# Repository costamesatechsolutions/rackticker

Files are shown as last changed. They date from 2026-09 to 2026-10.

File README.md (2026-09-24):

# RackTicker

**Rack enhancement that fits in 2U.**

**By Pine Heights Ventures LLC dba [Costa Mesa Tech Solutions](https://github.com/costamesatechsolutions)**

RackTicker cycling through its screens on live data

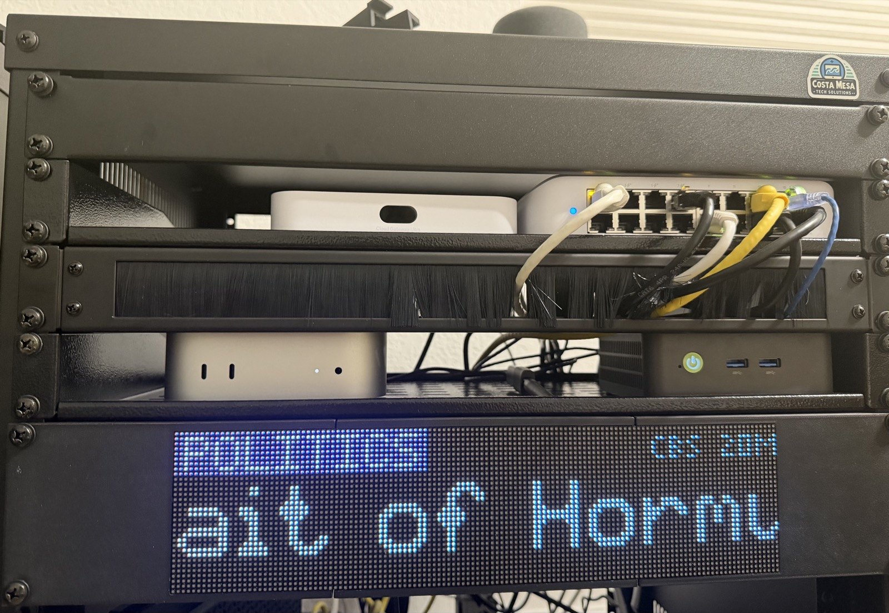
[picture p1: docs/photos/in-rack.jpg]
RackTicker installed in a 19-inch rack


Live LED signage for your server rack. RackTicker turns two 64×32 RGB LED panels and a
Raspberry Pi into a 128×32 ticker that lives in a 19-inch rack: stock tape, odds boards,
news, flights overhead, weather and a pixel town, with more in the community catalog.
Every screen is a plugin, the bundled data sources are free and need no key, and nothing
needs a cloud account. Run it on your computer first: the browser emulator shows the exact
pixels the panels will.

To write your own screen, fork the
**[plugin starter](https://github.com/costamesatechsolutions/rackticker-plugin-starter)**
or run `python -m app.dev new my_plugin`. See [Make a screen](#make-a-screen).

## Screens

| Screen | What it shows |
| --- | --- |
| Stock tape | The day's movers and your watchlist with company names, sparklines and each company's latest headline, under a flipping index header |
| Sportsbook | A Vegas odds board: spreads, totals and moneylines, big live scores with the bases, count and outs or the down and distance, banners for big plays, fireworks when your team scores |
| News desk | Network channels with whole headlines two lines at a time, a TV lower third or a Times Square zipper |
| Flights | The planes overhead: airline mark, flight number and route, then destination, aircraft, altitude and time to go; a list when several are about, a fly-by when one is directly overhead. Local ADS-B receiver or a free network feed |
| Weather | Animated sky, hourly chart and four-day forecast |
| Pixel Town | A small town on real time in three districts: a beach with the real tide and swell, a high street with a taco truck and your weather, and a station with real departures. The panel is a camera that drifts between them. The beach and station use the Surf and Departures plugins when installed |
| Clocks | Desk clock (with a 4:20 surprise) and TIX Clock |

**[Community plugins](https://github.com/costamesatechsolutions/rackticker-community-plugins)** live in their own repository and install from the
Plugins page with one click:

| Plugin | What it shows |
| --- | --- |
| [Departures](https://github.com/costamesatechsolutions/rackticker-community-plugins/tree/main/plugins/departures) | Live station boards: the London Underground in its own line colours, Metrolink and Amtrak across the United States, BART, and Budapest-Keleti, Roma Termini, Milan, Florence, Venice, Naples and Zürich, each in its country's style, with real delays, platforms, station announcements, and trains pulling in |
| [Onboard](https://github.com/costamesatechsolutions/rackticker-community-plugins/tree/main/plugins/onboard) | The strip map above the carriage doors of a train that is really running: the line, its stops, the train sliding along it, the next stop and how long until it |
| [Tanks](https://github.com/costamesatechsolutions/rackticker-community-plugins/tree/main/plugins/tanks) | California's reservoirs, and the space station's urine and water tanks, as sloshing water |
| [Quakes](https://github.com/costamesatechsolutions/rackticker-community-plugins/tree/main/plugins/quakes) | Earthquakes around you from the USGS on a 24-hour seismograph |
| [Surf](https://github.com/costamesatechsolutions/rackticker-community-plugins/tree/main/plugins/surf) | Wave height, swell, water temperature and the tide at your break: the sea sits high or low with the real tide, with the next turn and which way it is going |
| [Now playing](https://github.com/costamesatechsolutions/rackticker-community-plugins/tree/main/plugins/now_playing) | The song you're listening to like an old car stereo: album art, scrolling title, track and time, spectrum analyser. Spotify or Home Assistant |
| [Virtual Aquarium](https://github.com/costamesatechsolutions/rackticker-community-plugins/tree/main/plugins/virtual_aquarium) | A tank of clownfish, angelfish and neon tetras, with swaying plants and a wandering snail |
| [Retro Screensavers](https://github.com/costamesatechsolutions/rackticker-community-plugins/tree/main/plugins/retro_savers) | 3D pipes, Mystify, a starfield, a bouncing badge and marquee text |
| [Arcade](https://github.com/costamesatechsolutions/rackticker-community-plugins/tree/main/plugins/arcade) | Pixel Quest, Tetris, Snake, Breakout, Invaders and Pong, played live by AIs |
| [Formula 1](https://github.com/costamesatechsolutions/rackticker-community-plugins/tree/main/plugins/f1) | A start-light gantry counting down to lights out, the last race's podium and the championship fight |
| [Prediction markets](https://github.com/costamesatechsolutions/rackticker-community-plugins/tree/main/plugins/markets) | Polymarket and Kalshi: each question whole and still, then its odds slide up |
| [LED sign](https://github.com/costamesatechsolutions/rackticker-community-plugins/tree/main/plugins/ticker_wall) | Your own words on a storefront sign: letters that assemble, drop and spin, in taqueria, Vegas, arena and Times Square styles |
| [Freeway traffic](https://github.com/costamesatechsolutions/rackticker-community-plugins/tree/main/plugins/traffic) | California freeways near you: CHP incidents, the real overhead message signs, and travel-time signs as they read over the road |
| [Data from a link](https://github.com/costamesatechsolutions/rackticker-community-plugins/tree/main/plugins/url_data) | Any value from a JSON address as a big card, no code |

Screens finish the headline, card or lap they are showing before the playlist moves
on, skip themselves when they have nothing to show, and move on a frame-locked clock
so crawls step exactly one LED per frame.

## What you need

| Part | Notes |
| --- | --- |
| **Raspberry Pi 3A+** | The reference build. A Pi Zero 2 W should work (untested); the original Zero W is too slow |
| **2 × Waveshare 64×32 P2.5 RGB LED matrix panels** | HUB75, chained side by side: 320 × 80 mm of screen |
| **WatangTech RGB Matrix Adapter Board** | Sits on the Pi's header and drives the panels ("regular" pin mapping) |
| **5 V power supply with a barrel plug** | Sized for your panels; 4 A or more is a good start. Match the adapter's jack |
| **microSD card** | 16 GB or more, Raspberry Pi OS Lite |
| **3D printed 2U rack face** | Four parts and eight M3 × 10 screws; 88 mm of rack height. **[Print files on MakerWorld](https://makerworld.com/en/models/3327605-rackticker-2u-led-ticker-for-your-server-rack)**; guide in [BEZEL_V10.md](hardware/enclosure/BEZEL_V10.md) |
| **USB ADS-B receiver** *(optional)* | An RTL-SDR stick and antenna for planes overhead; without one, Flights uses a free network feed |

The panel frame is always exactly 128×32 RGB. Typography, clipping and motion are
designed at that size, so what the emulator shows is what the panels show.

| The 2U face | Behind it |
| --- | --- |
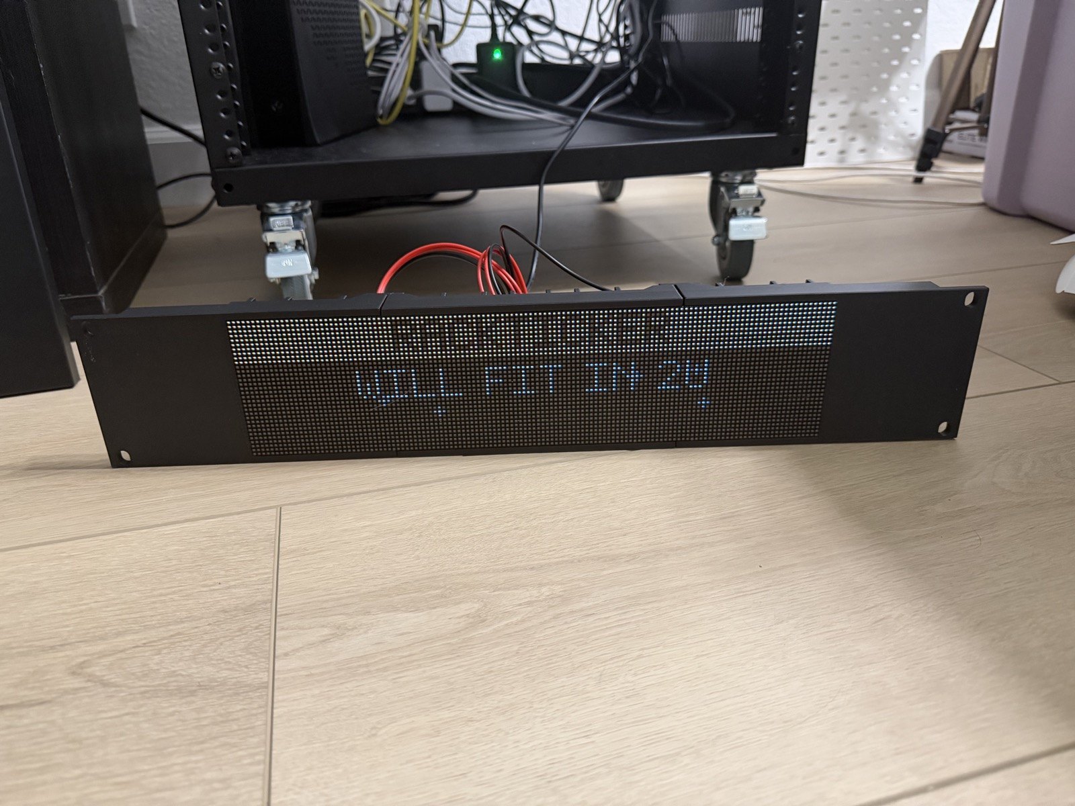
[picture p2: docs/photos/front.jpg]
The printed 2U face
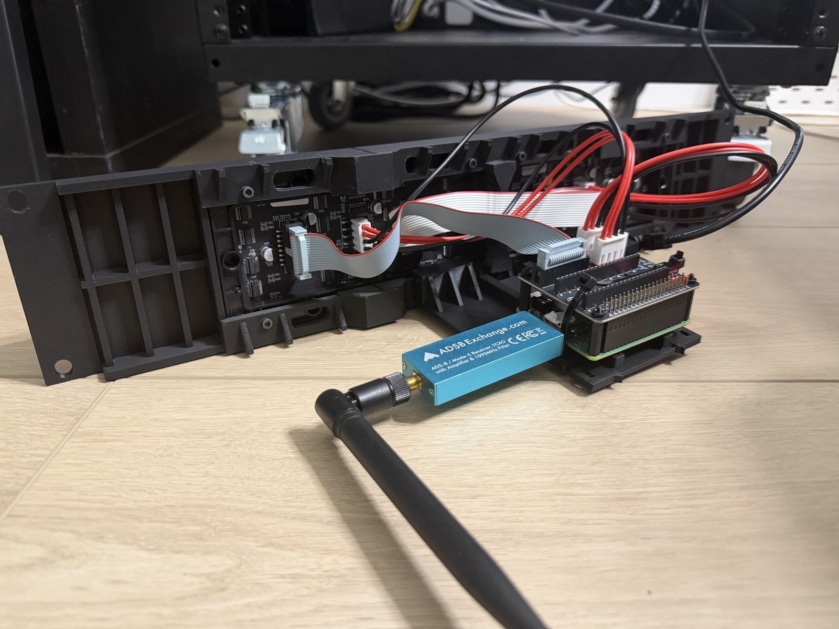
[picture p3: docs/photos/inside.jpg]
The Pi, adapter board and ADS-B receiver behind the face
|  |  |

Two panels, the adapter board on the Pi's header, one barrel jack for power, and
an ADS-B stick if you want the planes overhead to be the ones actually overhead.

The whole build in order, from printing to first light, is in [docs/assembly.md](docs/assembly.md).

## Try it on your computer

Python 3.10 or newer:

```sh
python3 -m venv .venv
source .venv/bin/activate
python -m pip install -r requirements.txt
python -m app
```

Open **http://localhost:8080/**. On your own computer the control page is on port
**8080**. (Installed on a Pi it is on **8081**; see below.) The first run starts a
playlist of real screens and asks where the rack is.

Windows PowerShell:

```powershell
py -3.12 -m venv .venv
.venv\Scripts\python.exe -m pip install -r requirements.txt
.venv\Scripts\python.exe -m app
```

`python -m app --help` lists options (`--port`, `--config`, `--host 0.0.0.0` to
open it to your LAN, `--output hub75` on a Pi).

## Install on a Pi

1. With [Raspberry Pi Imager](https://www.raspberrypi.com/software/), flash **Raspberry Pi
   OS Lite (64-bit)**. Under Edit Settings, set a hostname (for example `rackticker`),
   a user and password, your Wi-Fi, and enable SSH.
2. Boot it, SSH in once, and run:

   ```sh
   curl -fsSL https://raw.githubusercontent.com/costamesatechsolutions/rackticker/main/tools/install.sh | sudo bash
   ```

   It builds the panel driver, reboots, and installs the newest release by itself
   (about ten minutes on a Pi 3A+).

3. **Open the control page at `http://<your-pi>:8081/`** (port 8081, not 8080). The panels
   show the address when they light up, by name and by IP: `rackticker.local:8081` or
   `192.168.1.50:8081`. The name is the hostname you set in the imager. If `.local` does not
   resolve (some Windows and Android setups), use the IP.

That is the last time you need SSH:

- **Updates:** Settings → Software shows when a new version is out; press Update.
  The new version is installed beside the running one, and if it does not come up
  healthy within a minute RackTicker switches back to the old one by itself.
- **Self-healing:** every day, and at boot, RackTicker checks its installed files
  against fingerprints taken at install and repairs anything damaged, from the
  previous version or a fresh download.
- **Wi-Fi setup mode:** with no Wi-Fi saved, or after five minutes without the
  saved one (new router, new password, moved house), the panel shows
  **Wi-Fi setup**: join the `RackTicker-Setup` network with your phone, pick your
  Wi-Fi on the page that opens, and it reconnects. If the old network comes back,
  it rejoins by itself. A working connection is never touched.
- **Reset:** Settings → Software, as far back as you like. *Settings and plugins*
  keeps a backup of your old settings and leaves Wi-Fi alone; *Wi-Fi only* forgets
  the network and opens setup mode, for when RackTicker moves house without you;
  *Everything* clears settings, plugins, the password and Wi-Fi; *Ready to pass on*
  does all of that and then some (see below).
- **Password:** optional, in Settings → Software. Forgot it? Unplug RackTicker as soon
  as its panel lights up, three times in a row; on the next start the panel says
  PASSWORD CLEARED. No computer needed.
- **Crash protection:** if RackTicker keeps stopping, it goes back to the previous version.

### Passing one on, or cloning cards

**Settings → Software → Reset → Ready to pass on** hands a unit over clean. It clears
settings, installed plugins, plugin logins, the control page password and the saved Wi-Fi,
wipes the system log and shell history, and clears the device's own identity (machine id,
ssh host keys and name). Then it powers off; wait for the panel to go dark before
unplugging.

Cards cloned from one image without that step share a machine id, ssh host keys and
`.local` name, so the Pis clash on a network. After *Ready to pass on*, each card's first
boot makes its own and names itself from its Pi's serial number (for example
`rackticker-3c4d`). The panel shows the name and address it settled on.

To make a master card: set one up, reset it *Ready to pass on*, then image the card once
it has powered off.

**Developing from a computer:** `RACKTICKER_PI_HOST=pi@rackticker.local ./tools/deploy_pi.sh`
installs your committed working copy the same way, with the same health check and rollback.

## Panel tuning

The companion accepts every standard `rpi-rgb-led-matrix` `--led-*` flag from
`/etc/rackticker/matrix.conf` (installed once, never overwritten by updates);
restart it with `sudo systemctl restart rackticker-matrix` after editing.

- **Flicker:** the default `--led-limit-refresh=120` holds one steady refresh rate.
  Unlimited, the reference build swung from 208 Hz down to 93 Hz whenever the Pi was
  busy decoding ADS-B, which shows as bursts of flicker. Measure your panel with
  `--led-show-refresh` and keep the limit below its lowest rate.
- **Colours:** press **Settings → Developer tools → Colour test** and check each block matches its label. If
  GREEN shows blue (and amber looks pink), your panels are wired RBG: add
  `--led-rgb-sequence=RBG`.
- **Dim colours:** `--led-pwm-lsb-nanoseconds=160` (the default here) keeps very low
  brightness from drifting pink.
- **Other hardware:** for example an Adafruit bonnet:
  `--led-gpio-mapping=adafruit-hat --led-rows=32 --led-cols=64 --led-chain=2`.

## The control page

- **Now**: the live panel, what is playing, Pause and Next, a tile per screen to
  put it up now, panel on/off, brightness and a quick message.
- **Screens**: the playlist. Switch screens on and off, set their seconds, reorder,
  and open any screen's settings: team pickers by name, league chips, city search.
- **Plugins**: switch plugins on and off, install from a GitHub link or the
  community list, update, restart, remove.
- **Settings**: home location, brightness and night dimming, transitions, Home
  Assistant, and developer tools.

The page is open by default and binds to `127.0.0.1` unless you pass `--host` (the Pi
install passes it, so the page is on your network). Set a password under
Settings → Software if you want one. Everything the page does is also a small JSON
API under `/api/`.

## Home Assistant and voice

Settings → Home Assistant connects RackTicker to an MQTT broker (the Mosquitto
add-on works). It appears in Home Assistant as a device by itself: a light for on/off
and brightness, a Screen picker, a **Show …** switch for every screen, Next and a
Message box. Expose those switches to Alexa or Google through Home Assistant (or its
Matter bridge) and say "turn on Show Sportsbook".

## Make a screen

A plugin is a folder with a `plugin.json` and a Python file; you never edit RackTicker
itself. Fork the
**[plugin starter](https://github.com/costamesatechsolutions/rackticker-plugin-starter)**
or scaffold your own:

```sh
python -m app.dev new surf_report           # a working starting point
python -m app.dev check surf_report         # renders preview.png / preview.gif and reports problems
python -m app.dev preview surf_report       # live in the browser, reloads on save
python -m app.dev push surf_report --to rackticker.local:8081
```

Share it as a folder in a public GitHub repository: anyone installs it by pasting the link
into **Plugins → Add a plugin**, and updates it with one click. Installed plugins run in
their own sandboxed process, so a crash or hang restarts only that plugin and the display
never waits for it. The scaffold includes an `AGENTS.md` with the panel's rules, so an AI
coding agent can build and check a screen on its own. To list yours for everyone, open a
pull request against the
**[community plugins repository](https://github.com/costamesatechsolutions/rackticker-community-plugins)**
with one folder and one catalog entry. Full guide: [docs/plugins.md](docs/plugins.md).

## How it stays smooth

Animation time is counted in integer units, so a 30 px/s crawl at 30 fps moves one
LED every frame for weeks. Data providers run on their own thread and hand feed
parsing to a helper process, so a 1 MB market feed never freezes a frame; installed
plugins run in their own processes entirely. Frames slower than 25 ms and loop
stalls are recorded under `perf` in `/api/state`. Details:
[docs/architecture.md](docs/architecture.md).

Rendering runs as an unprivileged service. A small root-owned C++ companion alone owns the
GPIO and takes frames over a local socket, and the updater and network keeper are separate
root services the web page can only ask.

## Develop

```sh
python -m unittest discover -s tests -t .
python -m tools.render_demo          # regenerate docs/demo.gif from live data
```

See [CONTRIBUTING.md](CONTRIBUTING.md) and [AGENTS.md](AGENTS.md).

## License

AGPL-3.0-only. Copyright (c) 2026 RackTicker contributors. The original fonts and
assets are covered by the same license; dependencies keep their own. The control
page links to the license and a source archive of the running core. See
[LICENSE](LICENSE) and the [plugin licensing notes](docs/plugins.md#licensing-and-source).

The printable enclosure (`hardware/`) is licensed separately under
[CC BY-NC-SA 4.0](https://creativecommons.org/licenses/by-nc-sa/4.0/): print it, remix it,
share it, but don't sell it.

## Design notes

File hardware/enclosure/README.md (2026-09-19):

# RackTicker 2U enclosure

**[Print files on MakerWorld](https://makerworld.com/en/models/3327605-rackticker-2u-led-ticker-for-your-server-rack)** · **[BEZEL_V10.md](BEZEL_V10.md)** is the release: what to buy, how to print, how to
assemble. Four printed parts (face end ×2, face centre, Pi cradle), eight M3 × 10
screws and four rack screws turn two 64×32 P2.5 panels into a 19-inch, 2U rack face.

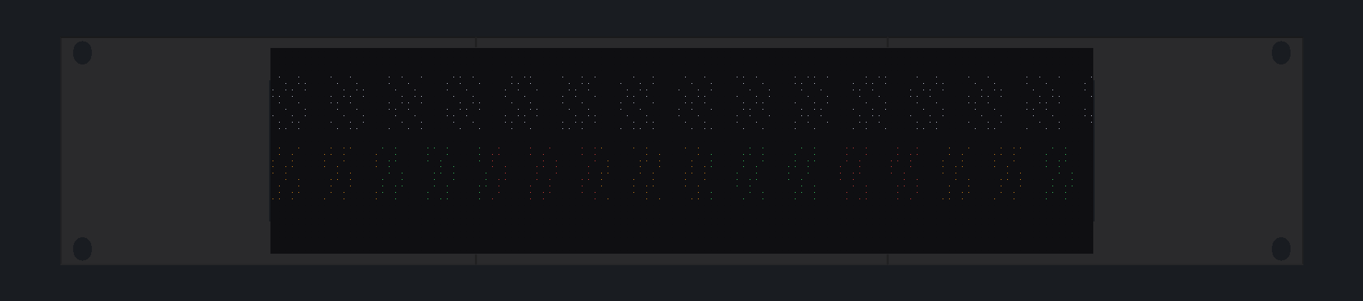
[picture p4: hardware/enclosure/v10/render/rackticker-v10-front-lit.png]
RackTicker V10 front


| Folder | What |
| --- | --- |
| `v10/3mf/` | Print files, oriented and ready to slice (Bambu Studio and others) |
| `v10/stl/` | The same parts as STL |
| `v10/step/` | STEP for editing in Fusion, FreeCAD or Onshape |
| `v10/assembly-stl/` | The parts placed as assembled, for a quick look |
| `v10/render/` | The renders above |

The parts are generated from source. To change a dimension, edit
`rackticker_v10_params.py` and rebuild (CadQuery runs in its own environment):

```sh
python3 -m venv cadenv && ./cadenv/bin/pip install -r hardware/enclosure/requirements-cad.txt
./cadenv/bin/python hardware/enclosure/build_bezel_v10.py
./cadenv/bin/python hardware/enclosure/validate_bezel_v10.py   # 94 checks: fit, walls, loads
```

`MEASUREMENTS.md` records the measured panel and rack dimensions the design is
built on; `v10/VALIDATION_V10.md` is the latest validation report.

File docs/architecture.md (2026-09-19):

# Architecture

How RackTicker turns data into a 128×32 frame and keeps it smooth.

## Files

```text
app/
  core/
    config.py          strict defaults, validation, atomic JSON persistence
    fonts.py           original MIT 5×7 bitmap glyphs at 1× / 2× / 3×
    models.py          normalized immutable provider snapshots and event models
    playlist.py        playlist entry model; repeated modules have distinct IDs
    scheduler.py       deterministic dwell, conditions, interrupt/resume
    renderer.py        canonical frame, clipping, scrolling, pixel transitions
    runtime.py         provider polling, rendering, failure isolation, exports
  modules/
    base.py            render context, availability, cadence, event priority
    clock.py           large clock, local date, 12/24h, optional seconds
    tixclock.py        counted-square clock with deterministic reshuffling
    flights.py         route, detail, and distance layouts
    sports.py          generic teams, high-contrast scores, game state
    message.py         static alert or reusable nonblocking ticker
    system_status.py   concise optional mock connectivity/temperature
  providers/
    base.py            FlightProvider, SportsProvider
    mock_flights.py    normalized mock ADS-B-style scenarios
    mock_sports.py     pregame/live/final/goal examples
  outputs/
    base.py            FrameSink contract
    browser.py         bounded latest-frame WebSocket fan-out
    hub75.py           Unix-datagram sink for the privileged matrix companion
  web/
    server.py          aiohttp routes, lifecycle, WebSocket transport
    static/            index.html, styles.css, app.js; no build step
  main.py              CLI entry point
config/
  config.example.json  complete example, checked by tests
  config.json          generated user config, gitignored
docs/
  integrations.md     future adapters and event boundary
  frames/             native example PNGs, including flight variants
  frames.png          nearest-neighbor contact sheet
tests/                unit and HTTP/WebSocket integration tests
tools/
  render_examples.py  regenerate the example gallery
  benchmark.py        local render-loop CPU/cadence measurement
requirements.txt      two direct runtime dependencies: Pillow, aiohttp
pyproject.toml        optional packaging and rackticker CLI
LICENSE               AGPL-3.0-only project license
```

```text
provider I/O ──> normalized Snapshot ──> Module.render(context)
                                              │
playlist / priority scheduler ─────────────────┘
                                              ▼
                              Pillow RGB frame, 128×32
                                              │
                              integer pixel transition
                                              ▼
                                  canonical framebuffer
                                     │              │
                              BrowserSink             Hub75Sink
                                     │              │
                               RGB888 / ws     SetImage(frame)
                                     ▼              ▼
                              browser canvas    physical panels
```

Modules only receive normalized state and render Pillow images. They cannot
call APIs or produce HTML. The runtime validates frame dimensions and RGB mode.
Every sink receives the same image object, and sinks must not mutate it.
Pillow and aiohttp usage follows their [image documentation](https://pillow.readthedocs.io/en/stable/reference/Image.html)
and [server documentation](https://docs.aiohttp.org/en/stable/web_quickstart.html).

## Scheduling and failure handling

- A playlist entry plays only while `Module.available(context)` is true, so a
  screen with nothing to show (no game on, no plane nearby) waits its turn.
  Disabled entries/modules are skipped. An empty eligible playlist shows a small
  idle screen and remains controllable.
- Modules declare `event_priority`. Message=30, flight=20, sports=10. Higher
  priority events can interrupt an interrupt; equal/lower events are coalesced
  while one is active. The suspended stack is bounded to eight. No stale backlog.
- Interrupt completion resumes exact elapsed dwell. Explicit Next discards
  suspended state. Saving a changed playlist retains a valid current entry when
  possible and clears suspended interrupts. Preview dwell is indefinite.
- Provider polling runs in a separate asyncio task every five seconds, with a
  six-second timeout. Provider errors retain the latest data and mark it stale;
  the screen explicitly displays **STALE / CACHED**. Snapshots older than 30
  seconds are also stale. Caches are in memory only and reset on restart.
- A module render/availability exception logs once and skips it for 30 seconds.
  Other screens, including the local clock, keep running. A failed sink is
  removed from active output until restart.
- Simulated internet/HA status is illustrative data. It does not control the
  real computer's network, and it does not imply an actual HA connection.
  **Simulate provider outage** independently exercises provider degradation.

## Rendering and performance

All coordinates land on integer pixels. Original 5×7 glyphs scale to 10×14 and
15×21 with no antialiasing. Strings use a bounded mask cache. Sports/status
render only when data or settings change; the clock checks once per second.
Moving screens are capped at the configured 5–30 fps (default 25). Scrolling
uses elapsed time, a configurable speed and gap, and an explicit clipping box.
Debug animation speed changes motion, not timekeeping or playlist dwell.

The TIX Clock follows the original field proportions: 1×3, 3×3, 2×3 and 3×3
for HH:MM. Each field lights the number of squares represented by its digit; a
local seeded permutation changes the occupied squares on the original clock's
default four-second cadence. That keeps the display playful while making every
output sink deterministic.

Transitions are cut, slides, wipe, dissolve and drop; all transition frames are
native 128×32 RGB, including exports taken mid-transition.

Smoothness is engineered, not hoped for. Animation time is counted in integer
units, so a 30 px/s crawl at 30 fps moves exactly one LED every frame for weeks
on end. Providers hand JSON/XML parsing and image decoding to
`rackticker.offload()`, which runs it in a helper process, so a 1 MB market feed
never freezes a frame. Frames slower than 25 ms and loop stalls are recorded
with the screen and the providers refreshing at the time, visible under `perf`
in `/api/state`.

WebSocket binary messages are exactly **12,288 bytes**, row-major RGB888 without
a header. JSON text messages carry runtime metadata. Unchanged pixels are not
rebroadcast. Each client has a single latest-frame notification; slow clients
drop intermediate frames rather than building queues. Sends time out after two
seconds; at most 12 clients are allowed. No browser is required for the renderer
to run. The short export history is bounded to about 360 KiB of RGB data.

```sh
python -m tools.benchmark --seconds 10
```

This reports CPU consumption and output-frame counts for static and scrolling
screens on your current machine. Pi performance and electrical refresh must
still be measured on the target hardware; workstation results are not Pi claims.

## Plugins

Bundled plugins load in-process from `plugins/`; installed plugins run in
`app/sandbox_child.py` processes managed by `app/core/sandbox.py`. See
[plugins.md](plugins.md) for the contract and the sandbox.

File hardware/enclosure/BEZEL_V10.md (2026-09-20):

# RackTicker 2U bezel — V10 (release)

A 19-inch, 2U rack face for two 64×32 P2.5 HUB75 LED panels, driven by a
Raspberry Pi 3A+ with an RGB matrix adapter board. The front is solid black except for the
screen, and it's built from 4 printed parts, 8 screws and 4 rack screws.

front
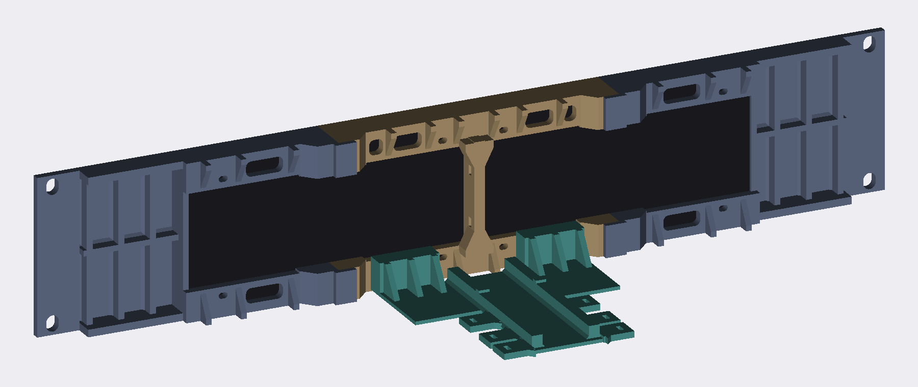
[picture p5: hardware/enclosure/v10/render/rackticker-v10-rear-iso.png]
rear


---

## What you need

| | Qty | Notes |
|---|---:|---|
| Waveshare RGB-Matrix-P2.5-64×32 panel | 2 | Comes with its ribbon and power leads |
| Raspberry Pi 3A+ | 1 | A Pi Zero 2 W should work too (untested) |
| WatangTech RGB Matrix Adapter Board | 1 | The HUB75 adapter ("regular" pin mapping) |
| microSD card, 16 GB or more | 1 | Raspberry Pi OS Lite |
| 5 V power supply, barrel plug | 1 | 5 V, sized for your panels (4 A or more is a good start). Match the adapter's jack (usually 5.5 × 2.1 mm) |
| **M3 × 10 screw, socket cap or pan head** | **8** | **not countersunk**; buy a 10- or 25-pack |
| rack screws | 4 | whatever your rack takes; corners only |
| zip tie, 2.5–4.8 mm | 1–3 | holds the Pi on the cradle; one in the middle is enough |
| matte PLA | ≈ 220 g | PETG works too |

**Nothing threads into plastic.** All 8 screws go into the brass inserts in the
panels. The printed parts hold each other with jigsaw keys and dovetails.

---

## Print

Each file is already oriented and centred. **Open, slice, print. Don't
rotate, and don't use auto-orient.**

| File | Print | Supports | Brim |
|---|---:|---|---|
| `v10/3mf/rackticker-face-end-v10b.3mf` | **×2** | build plate only | 5 mm outer |
| `v10/3mf/rackticker-face-centre-v10.3mf` | ×1 | build plate only | 5 mm outer |
| `v10/3mf/rackticker-pi-cradle-v10.3mf` | ×1 | **OFF** | none |

> **The cradle must print with supports OFF.** Its two dovetail slots open onto
> the bed, and "build plate only" supports would fill them solid. The slot
> roofs are short bridges that PLA prints fine without support.

0.20 mm layers · 5 walls · 6 top/bottom · 30 % gyroid · elephant-foot
compensation on (default) · seam at rear.

`face-end-v10b` replaces the first V10 end part: its joint node is raised
to meet the cap, so the top is one flat surface instead of having a 3 mm step.
Nothing the centre part touches changed, so `face-centre-v10` and
`pi-cradle-v10` are unchanged and fit either end part.

The two face-end prints are identical. One goes on the left and one on the
right, installed upside down relative to each other. The part is symmetric top
to bottom, so it fits either way.

After printing, snap the supports off the rear plates and push an M3 screw
through every slot to be sure none is blocked.

---

## Assemble

Lay both panels **face down** on a towel, butted together at the seam.

1. **face-centre** goes on first, straddling the seam. Fit its 4 screws loosely.
2. **face-end ×2**: lower each one straight down so its two jigsaw keys drop into
   the sockets in the centre part. Fit 2 screws each, loosely.
3. Push the panels together so the seam is closed, check the black gap around
   the screen looks even, then **tighten all 8 screws by hand**. Each screw has
   exactly 5 mm of thread in the panel, so don't power-drive them.
4. **Pi**: drop the Pi 3A+/HAT into the cradle with **USB toward the open rear**.
   The micro-SD and the HAT's DC jack then face the panels, and the cradle
   leaves 38 mm of room there. Put one zip tie through the middle pair of
   slots, over the HAT.
5. **Cradle**: hold it above its two rails on the centre part and slide it
   straight down until it stops. It hangs by gravity, so no screw is needed.
6. Route the panel power leads through the two tie slots in the centre fin.
7. Lift into the rack and fit the 4 corner rack screws.

**Service:** the Pi sits in front of the two lower centre screws. Lift the
cradle off its rails by hand to reach them.

---

## What was verified

`validate_bezel_v10.py` runs **94 checks, all passing**, against the exported
files the slicer gets, not the CAD model. Full table:
[`v10/VALIDATION_V10.md`](v10/VALIDATION_V10.md).

- every printed part is exactly **one connected solid**, watertight, and fits
  the A1 Mini bed
- **0.0000 mm³** of plastic inside either LED panel's space
- **exactly 5.000 mm** of material at all 8 screws, and every screw path open
- **nothing touches the panel back** where the connectors are
- **0 open points** outside the screen opening, a 0.40 mm gap around the
  screen, and the rack interior fully hidden
- the Pi + HAT stack fits, with the Pi's power side, the HAT's jack side, the
  USB end and the micro-SD end all clear
- **jigsaw keys** fully engaged, with at most 0.25 mm of play and 4.75 mm walls
- **no section thinner than 3.0 mm** (about 7 printed lines), checked on every
  0.6 mm slice of every part
- **the assembly moves themselves**: the cradle slides onto its rails and each
  end part drops onto its keys, checked in 0.5 mm steps with zero collision
- a **hex key reaches all 8 screws** in a straight line (the two lower
  centre ones once the cradle is lifted off)
- **all 8 installed screw heads clear the cradle**, both hung in place and
  along its whole slide-down path
- no floating islands in any sliced layer

**Hand strength calculations, matte PLA** (in-layer 35 MPa, across layers 12 MPa):

| Load | Safety factor |
|---|---:|
| 50 N push on the middle of the screen, bezel only (panels ignored) | 4.1 |
| that push pulling on a jigsaw key | 17.2 |
| 20 N pressing on the Pi while plugging in, 103 mm lever | 3.6 |
| cradle rail neck, loaded across layers | 48 |
| zip tie pulled hard | 5.0 |

---

## Source

Everything is parametric. One number changes one feature.

- `rackticker_v10_params.py`: every dimension, each with the reason for it
- `build_bezel_v10.py`: the CadQuery model, STEP, STL and 3MF export
- `validate_bezel_v10.py`: the 94 checks

```bash
python build_bezel_v10.py && python validate_bezel_v10.py
```

This needs the CAD environment in `requirements-cad.txt`.

Common tweaks:

| Want | Change |
|---|---|
| LEDs further back or forward | `LED_PROUD` |
| a looser or tighter screen gap | `AP_CLR` |
| a looser jigsaw fit | `KEY_CLR` |
| a looser cradle on its rails | `DOVETAIL_CLR` (sides and depth) |

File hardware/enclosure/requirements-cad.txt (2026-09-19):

# CAD toolchain for the v4 bezel (separate from the RackTicker application venv)
#   python3 -m venv cadenv && ./cadenv/bin/pip install -r requirements-cad.txt
cadquery>=2.5,<3
trimesh>=4.12,<5
manifold3d>=3.5,<4
shapely>=2.0,<3
numpy>=1.26
scipy>=1.13
matplotlib>=3.9
networkx
rtree
lxml

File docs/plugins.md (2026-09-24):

# RackTicker plugins — API v1

A plugin is a folder with a `plugin.json` and one Python file. It can add a
screen, a data source, or both. You never edit RackTicker itself.

## Five minutes to your own screen

From a RackTicker checkout (`python -m pip install -r requirements.txt`):

```sh
python -m app.dev new surf_report          # a working plugin to start from
python -m app.dev check surf_report        # render it: surf_report/preview.png + preview.gif
python -m app.dev preview surf_report      # live in the browser; reloads on every save
python -m app.dev push surf_report --to rackticker.local:8081
```

`push` needs **Plugins → For plugin developers → Allow plugin uploads** switched on
on the device. It installs or updates the plugin, switches it on and adds it to
the playlist; running it again replaces the old version in place.

`check` is made for AI coding agents as much as people: it prints timings and
problems (exceptions, black frames, slow frames) and writes images an agent can
look at. The scaffold includes an `AGENTS.md` with the panel's rules, so Codex,
Claude or Cursor can build a screen without a panel on the desk.

## Folder format

```
surf_report/
  plugin.json    {"id": "surf_report", "name": "Surf report", "entry": "plugin.py",
                  "description": "…", "author": "…", "version": "1.0.0", "homepage": "…"}
  plugin.py      defines plugin = Plugin("surf_report", ...)
  README.md      optional
```

`id` is lowercase letters, digits and underscores (48 max) and must equal
`Plugin.name`. `entry` defaults to `plugin.py`. Other files (images, data) can
sit alongside; read them relative to `Path(__file__).parent`.

## Sharing

Put the folder in a public GitHub repository (on its own, or as one folder of a
repository with several). Anyone can paste the link into **Plugins → Add a
plugin**: `https://github.com/you/repo` or `https://github.com/you/repo/tree/main/surf_report`.
RackTicker downloads that exact commit, checks it, loads it once in a sandbox,
and only then replaces any earlier version. **Update** fetches the newest
commit of the same branch; **Remove** deletes the folder and its settings.

To appear in **Community plugins** for everyone, open a pull request adding an
entry to [`community/index.json`](../community/index.json):

```json
{"id": "surf_report", "name": "Surf report", "author": "you",
 "description": "Wave height, period and water temperature from NOAA buoys.",
 "url": "https://github.com/you/repo/tree/main/surf_report"}
```

## Sandbox and trust

Installed plugins run outside the display's process: one process per plugin, or,
on machines with under 1.5 GB of memory (a Pi 3 has 512 MB), one process shared by
all installed plugins (`RACKTICKER_SANDBOX=shared` or `separate` to choose):
- The display never waits for them. An animated screen is drawn a few frames
  (four) ahead of the one on show, and the display shows the frame whose moment
  has come, so a late reply never shows as a hitch in a crawl; a slow plugin
  only makes its own screen late. Because of that, `render()` must depend only on
  its `context` (`animation_time`, `now`, `scene`, settings and snapshots), never
  on how many times it has been called or on `time.time()`. The previous screen
  stays up until a plugin's first frame is ready, so there is no black frame
  between screens.
- A crash, a hang (nothing heard from the process for 10 s while it owes a frame)
  or growing past its memory budget restarts the process, with a backoff; in
  shared mode the plugin responsible is named and the others simply come back.
  Five failures in ten minutes switch a plugin off and the Plugins page shows why.
- It runs at lower CPU priority, with a clean environment (no service
  credentials) and its own data folder as `HOME`.
- It sees its own settings and data only, not other plugins' data.

This contains mistakes; it is not a security boundary against malicious code.
A plugin can still reach the network and files the RackTicker service account
can reach (the systemd unit confines that account to its own data directory).
Install plugins from people you trust, the same as any software, and leave
uploads switched off when you are not developing.

Bundled plugins (the `plugins/` folder shipped with RackTicker) run inside the
main process, which lets them feed built-in screens (`provider_for`) and
outputs. pip-installed packages with a `rackticker.plugins` entry point (below)
also still work: switch them on with `--plugin NAME`.

## The Plugin object

`plugin.py` defines a `Plugin` from the public `rackticker` package:

```python
from rackticker import Plugin, Module, new_frame, centered

class Hello(Module):
    name = "hello"

    def render(self, context):
        frame = new_frame()
        centered(frame, context.config["plugins"][self.name]["message"], 12)
        return frame

plugin = Plugin(
    name="hello", label="Hello rack", api_version=1,
    module=Hello, defaults={"message": "HELLO RACK"},
)
```

The plugin id (`plugin.json` `id`), `Plugin.name` and the module's `name` must
match. Built-in names cannot be replaced by a screen plugin. Duplicate
IDs, competing providers for one target, and incompatible API versions are
reported rather than silently overwritten.

`Plugin` can provide any combination of these components:

| Component | Factory | Contract |
| --- | --- | --- |
| Screen | `module()` | A `Module` returning a new 128×32 RGB Pillow image |
| Data | `provider(plugin_context)` | A `Provider` whose async `fetch()` returns `Snapshot(data)` |
| Display | `output(plugin_context)` | A `FrameSink` consuming the canonical framebuffer |

### The display toolkit

Everything the built-in screens use is exported from `rackticker`, so a community
screen can look as good as the ones that ship:

| Tool | What it gives you |
| --- | --- |
| `Lettering(text, effect, palette, mode, seed)` | Animated words: `assemble` (pixels fly in), `drop`, `slot` reels, `typewriter`, `wave`, `scroll_stop`, `chomp`, `split`, `sparkle`, `fireworks`. Colour modes `solid`, `alternate`, `chase`, `rainbow`, `fire`, `gradient`. `.duration` tells you how long it runs. |
| `Storyboard` | Plays variable-length items back to back (headlines, cards, phrases), resumes where the last visit stopped, and never swaps data under an item on screen. |
| `Module.hold(context)` | Return `True` while mid-story so the playlist waits for the current item to finish (bounded by the scheduler). `Storyboard.hold()` implements it for you. |
| `draw_text(..., scale=2, smooth=True)` | Rounded Scale2x headline lettering; `draw_tiny` is a 3×5 font for dense tables. |
| `wrap_text(text, width, scale=1, mixed=False)` | Whole-word lines that fit `width` pixels. Long sentences read far faster as two lines that roll up than as one line crawling past. |
| `draw_text(..., mixed=True)` | Keeps lowercase, drawn like station dot-matrix boards with true descenders (a mixed line is 9 rows, not 7). Use it for names and sentences; keep codes, scores and prices in capitals. |
| `loop_strip`, `crawl_once_x` | Endless or one-pass crawls. Pre-render a strip once per data change; each frame is then just a paste. |
| `sprite(ascii_art, palette)`, `stamp` | Pixel-art sprites from strings, cached. |
| `Particles`, `bulb_border`, `chase_bar`, `triangle`, `hsv`, `mix`, `dim`, easing | Casino lights, confetti, market arrows and motion curves. |

Animated screens return `1 / context.config["display"]["fps"]` from
`refresh_interval`; static screens keep the default (redraw only when data or
settings change). Time comes from `context.animation_time`, which advances in
whole frames, so a crawl moving 30 px/s at 30 fps steps exactly one LED per frame.
Keep per-frame work small: the Raspberry Pi 3A+ runs every screen at 7–30% of one
core, and most of that budget belongs to pixels that actually change.

When a later version renames or retires a setting, supply
`migrate_settings(settings) -> settings` so saved configurations upgrade instead
of failing validation.

Factories must do no I/O or resource acquisition. Put network work in async
provider methods and acquire output resources lazily. Exported API v1 names
should be imported from `rackticker`; importing `app.core.*` couples a plugin to
internal implementation details. Normalized `Flight`, `Game`, `Team`, `Race`,
`Message`, `SystemStatus` and `PriorityEvent` models are also exported from
`rackticker`; generic screens can use their own data classes inside `Snapshot`
without changing the core.

### Settings

`defaults` is a flat mapping of up to 32 fields. Text, finite numbers and booleans
automatically become controls in the web UI. `choices={"mode": ("auto", "night")}`
turns a text field into a dropdown, and `help={"mode": "…"}` adds a one-line hint
under it. A `validate_settings(settings)`
callback can enforce ranges or lengths; raise `ValueError` with a useful message.
Type checks and unknown-field rejection apply before the callback. Invalid
updates leave the previous configuration untouched.

`ui` hints give a setting a better control in Settings:

| Hint | Control |
| --- | --- |
| `{"type": "slider", "min": 3, "max": 30, "step": 1, "unit": "s"}` | Slider with a readout |
| `{"type": "tags"}` | A comma-separated list edited as removable chips |
| `{"type": "multi", "options": ["NFL", "NBA"]}` | Pick several; stored comma separated |
| `{"type": "teams", "leagues": "leagues"}` | Team search by name (ESPN's list), stored as abbreviations |
| `{"type": "location"}` on `latitude` | City or ZIP search that fills `latitude` and `longitude` |
| `{"type": "secret"}` | A password box; the value is never sent back to the page |
| `{"advanced": True}` | Tucked under an Advanced fold (paths, poll timing) |
| `{"label": "Seconds per game"}` | Any hint can rename the field |

A plugin whose `latitude` and `longitude` are both 0 receives the device's home
location (Settings → Home) in `PluginContext.settings`, so most people never
enter coordinates twice.

Screen settings are in `context.config["plugins"][name]`. Provider and output
factories receive `PluginContext`; its `.settings` property returns current
settings, so read it when performing work rather than caching a copy at startup.
Mark tokens and API keys `{"type": "secret"}`: the page shows dots instead of the
value and `/api/config` never returns it. Do not put secrets in plugin defaults or
examples. A plugin that must keep something it learns (a rotated refresh token) can
write it under `Path.home()`, which for an installed plugin is its own data folder.

### Providers and events

By default a plugin's snapshots appear at `context.snapshots[plugin.name]`.
Set `provider_for="flight"` or `"sports"` to supply a built-in
screen with its existing normalized data model. For example, a local ADS-B
plugin can read `dump1090-fa` JSON and return a `Snapshot[Flight]`; the decoder
continues to own the SDR, and existing feeder services continue independently.

The current runtime polls providers every five seconds with a six-second timeout.
It retains the previous snapshot on error, marks it stale, and marks timestamps
older than 30 seconds stale. Preserve the source timestamp; do not label an old
receiver file as fresh merely because it was read now. Implement async `close()`
to release client sessions. Run blocking SDK calls in a worker thread and apply
their own timeouts: cancellation cannot forcibly stop arbitrary blocking code.

`plugin_context.emit_event(module_name, duration_seconds)` requests a priority
interrupt; the module's `event_priority` determines scheduling. Deduplicate events
and implement cooldowns in the provider. A provider calling this during `fetch()`
requests the event before its newly returned snapshot is stored; rendering begins
on a later runtime step. Use `Module.available(context)` for conditional playlist
entries. An interrupt resumes the existing playlist afterwards.

Parse big payloads with `offload`. A long `json.loads`, XML parse or image
decode holds Python's GIL, so even in a thread it freezes the display; on a
Raspberry Pi a 1 MB feed stalled the crawl for 300 ms. Download on the event loop,
then hand the bytes to a module-level function:

```python
from rackticker import offload

def parse(raw):                       # runs in a helper process
    return normalize(json.loads(raw))

rows = await offload(parse, await response.read())
```

The function and its arguments must be picklable (module-level functions in an
installed plugin are). When the helper cannot run it, for example for a plugin
loaded from a file path in tests, `offload` runs it in a thread instead, so your
code is the same either way.

### Outputs

Outputs receive the same 128×32 RGB image as the browser and PNG exporter, with
brightness supplied separately. They must not mutate the image. `display()` must
return promptly: use a bounded queue holding only the latest frame when hardware
needs a worker. Implement `close()` and accept repeated cleanup where practical.
Hardware libraries belong inside their plugin; importing RackTicker on a Mac
must not require GPIO or HUB75 drivers. Alternative mounts and output transports
are possible; arbitrary framebuffer resolutions are outside API v1.

## Failure behavior

Import and factory errors are shown on the Plugins page. A render exception
skips the screen for 30 seconds; provider failures keep the last data and mark
it stale. A bundled or pip plugin runs inside the main process, so an infinite
loop there would still stall the display; installed (folder) plugins are
isolated as described above. If a selected live provider fails to start, its
built-in mock is removed instead of masquerading as the real source.

Switching a plugin off keeps its settings and playlist entries (its screens are
skipped); switching it back on restores them. Switching a plugin on adds its
screen to the playlist once; nothing adds itself without being asked.

## pip packages

A plugin can also be a Python package installed with pip into RackTicker's
environment. Declare the entry point in its `pyproject.toml`:

```toml
[project.entry-points."rackticker.plugins"]
hello = "rackticker_hello:plugin"
```

and start RackTicker with `--plugin hello` (repeatable). Discovery reads package
metadata without importing code; only selected packages are loaded.
`examples/hello-plugin` is both a pip package and an installable folder. It is also
published on its own as the [plugin starter](https://github.com/costamesatechsolutions/rackticker-plugin-starter),
ready to fork and install straight from GitHub.

## Licensing and source

RackTicker and the example use `AGPL-3.0-only`, matching InkSlab's stated AGPL v3
choice. Commercial use is allowed. Distributed derivative versions carry the
license's corresponding-source obligations; modified versions used over a network
must offer their corresponding source to those users. See
[AGPL section 13](https://www.gnu.org/licenses/agpl-3.0.html#section13).

For closely integrated Python plugins, use AGPL-3.0 or a compatible open-source
license; permissive code can often be incorporated, but attribution still matters.
Do not assume every unrelated service communicating over HTTP must adopt this
license. License compatibility depends on how works are combined; GNU discusses
the distinction in its [plugin FAQ](https://www.gnu.org/licenses/gpl-faq.html#GPLPlugins).

The web footer offers the running core's source and license. The source ZIP uses
an explicit file allowlist and excludes private configuration, backups and
installed third-party plugins. Plugin authors/distributors must provide matching
plugin source separately. When shipping an assembled device or modified release,
include matching build/install instructions, dependency notices and the source
for the covered components. Keep historical license notices for previously
distributed versions; relicensing a new release does not revoke old permissions.

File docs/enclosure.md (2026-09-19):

# Enclosure

The printable 2U rack face lives in [hardware/enclosure](../hardware/enclosure):
start with [BEZEL_V10.md](../hardware/enclosure/BEZEL_V10.md).

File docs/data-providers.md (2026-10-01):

# Data providers

RackTicker separates screen modules from data providers. A module decides how
information looks; a provider supplies the information. This keeps the core
small and lets installations add local or hosted data sources as plugins.

## Aircraft

The bundled `local_adsb` plugin, shown as **Planes overhead**, finds aircraft in
this order:

1. **A receiver on the network**, when `receiver_url` is set to its
   `aircraft.json` address (PiAware: `http://piaware.local:8080/skyaware/data/aircraft.json`;
   readsb, tar1090 and ultrafeeder serve `/data/aircraft.json` or
   `/tar1090/data/aircraft.json`). The receiver's location comes from the
   `receiver.json` beside it, or the home location if there is none.
2. **A USB receiver on this Pi**, read from dump1090-fa's `aircraft.json` and
   `receiver.json`. It does not take over the SDR or change any feeders.
3. **Free community feeds** (adsb.lol, then adsb.fi) around the home location,
   when neither of the above answers. No hardware and no account needed.

The flight screen appears only when a tracked aircraft has useful data, so
disconnecting the SDR does not leave a dead page in the playlist.

## Sports

The built-in sports provider is demo data for testing layouts and a new panel.
The bundled `free_sports` plugin replaces it with key-free NHL, NFL, MLB and NBA
schedule and live-score data. It defaults to Anaheim, the Kings and the Padres;
live and nearby games rotate every eight seconds, followed by upcoming games for
favorite teams. Configure `leagues`, `favorite_teams`, `refresh_seconds`,
`cycle_seconds`, and `timezone` under `plugins.free_sports`. WNBA, college
football and men's college basketball can also be enabled. `show_logos` fetches
only the current matchup's provider-hosted marks into a bounded memory cache;
the project does not redistribute team artwork.

## News

The bundled `news` plugin reads standard RSS or Atom over HTTPS and displays a
Times Square-style headline ribbon. It defaults to a technology feed and stores
only a bounded in-memory headline list. Configure `feed_url`, `source_label`,
`refresh_seconds`, and `cycle_seconds` under `plugins.news`.

NHL data comes from the league's public web API. The other enabled leagues use
ESPN's key-free scoreboard web feed. ESPN does not publish a compatibility
contract for that feed, so the plugin treats it as a best-effort source and
keeps the other leagues working when one request fails.

## Formula 1

The community `f1` plugin shows the next race, circuit, round and local start time
using the open-source [Jolpica F1 API](https://github.com/jolpica/jolpica-f1).
It caches the schedule for 15 minutes by default. Configure `timezone` and
`refresh_seconds` under `plugins.f1`.

## Prediction markets

The community `markets` plugin rotates active public Kalshi and Polymarket
questions by recent activity. It displays the current implied YES probability
and does not contain authentication, wallet, order, or trading code. The feeds
are cached and partial failures are isolated, so one venue can remain on screen
when the other is unavailable. Configure `refresh_seconds` and `cycle_seconds`
under `plugins.markets`.

## Ticker scenes

The community `ticker_wall` plugin is a data-free presentation module with arena,
Times Square and taqueria scenes. Each scene accepts pipe-separated custom text,
and `auto` mode rotates all three. It deliberately animates small borders and
text rather than panel brightness, avoiding full-screen flashes.

The community `arcade` plugin adds original autonomous runner, platform and cap
shuffle scenes designed for the 128×32 display. It uses no ROMs, game assets,
network data or input device. `auto` rotates the scenes; each can also be held
individually.

## Finance

The bundled `finance` plugin shows stocks, funds, commodities and cryptocurrency
with price, daily percentage move and an intraday sparkline. Its default `auto`
mode discovers two liquid gainers, two liquid losers and one heavily traded
name, then adds the S&P 500, Bitcoin and crude oil. `custom` mode uses the
comma-separated `symbols` list. Quotes come from a key-free chart web feed and
are best-effort because that feed has no published compatibility contract.

## Weather

The bundled `weather` plugin uses the key-free Open-Meteo forecast API. It shows
a pixel-art condition graphic, temperature, feels-like temperature, wind,
sunrise and sunset. Defaults target Santa Ana and Fahrenheit; latitude,
longitude, units and refresh cadence are configurable.

Additional leagues need provider-specific plugins:

- [TheSportsDB](https://www.thesportsdb.com/documentation) offers a public v1
  API for basic development. Its live-score v2 endpoints require a premium API
  key, currently described on its official API page.
- [Sportradar](https://developer.sportradar.com/getting-started/docs/your-account)
  offers trial access after account registration and uses per-product API keys
  and quotas.

A provider plugin belongs under `plugins/<provider>/` and registers through the
public API in `app/plugin_api.py`. Keep credentials out of repository config:
read them from environment variables or a root-readable file on the device.

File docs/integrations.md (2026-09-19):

# Future integration boundary

RackTicker owns its clock, configuration, playlist, rendering, and outputs.
Home Assistant is an optional source of normalized information and events.
Losing an integration must never prevent standalone operation.

## Private data sources

Some data can only be used privately (a service licensed for personal projects,
or your own accounts). Keep such a source in its own private service and read it
from a private, installed plugin: the plugin lives in your own repository, is
installed with `python -m app.dev push`, and nothing about it ships with RackTicker.

## Providers

`FlightProvider` and `SportsProvider` expose async `fetch()`
and return `Snapshot[Flight | Game]` as appropriate. A snapshot contains
the normalized data, original update timestamp, source name, stale flag, and an
optional error. The runtime polls separately from rendering, bounds request
time, retains the last successful data on error, and adds visible stale labels.

The `local_adsb` plugin can optionally enrich the nearest aircraft through
ADSBDB. It queries the combined aircraft/callsign endpoint, caches successful
responses for six hours, and retains normal local receiver output when the
service is unavailable or does not know a callsign. Origin and destination are
shown as IATA codes when available. The displayed ETA is a rough estimate from
remaining great-circle distance and current ADS-B ground speed; it is not a
scheduled or airline-provided arrival time. Set `route_lookup` to `false` for a
fully local-only installation.

For a real integration, put vendor schema conversion beside its provider. Keep
credentials outside committed configuration (environment variables or a local
secret file). Preserve upstream data timestamps instead of stamping old cached
responses as newly live. Apply provider-specific age thresholds and rate limits
when those API contracts are known. Add persistent caches only when useful.

## Events

The current event contract is `PriorityEvent(module, duration, priority, reason)`.
The scheduler suspends its exact cursor and resumes it after the interrupt.
Modules declare their default priority; conditional eligibility is independent.

Before enabling real automatic events, add an adapter-level stable event ID,
timestamp/TTL, and a bounded deduplication/cooldown policy. Examples: one overhead
event per aircraft passage, or one event per game/score revision. Current manual
events are intentional developer actions, and equal/lower priority interruptions
are coalesced while another event is active.

## REST / generic JSON

A later authenticated `/api/events` route can normalize a bounded payload into
`Message` plus `PriorityEvent`, or update an existing provider snapshot. Validate
event timestamps, input size, module IDs, and duration. Use a local bearer token
or an authenticated reverse proxy before accepting external automation traffic.
The current `/api/scenario` route is for mock development and is not that public
contract. It does not call any third-party service.

Example future message payload:

```json
{
  "event_id": "garage-open-20260912T152400",
  "module": "message",
  "title": "GARAGE",
  "text": "DOOR OPEN",
  "duration_seconds": 10
}
```

## MQTT / Home Assistant

An optional async MQTT adapter could subscribe to `rackticker/events` and publish
device availability. Both REST and MQTT should feed the same normalization/event
adapter. HA discovery and controls can then sit on top of that small contract.
Reconnect with backoff, make stale/unknown status explicit, and expire retained
alert messages before scheduling them. Do not put an MQTT client or HA dependency
inside visual modules or make broker/HA availability a startup prerequisite.

No MQTT client, HA discovery, authentication, or generic external event endpoint
is implemented in Milestone 1.

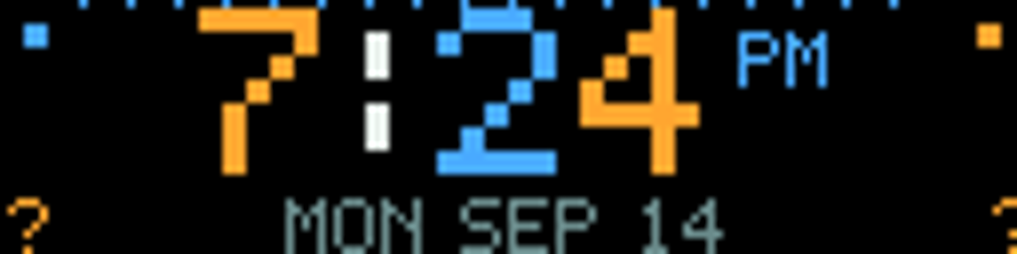
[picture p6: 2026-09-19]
docs/frames/clock-desk.png

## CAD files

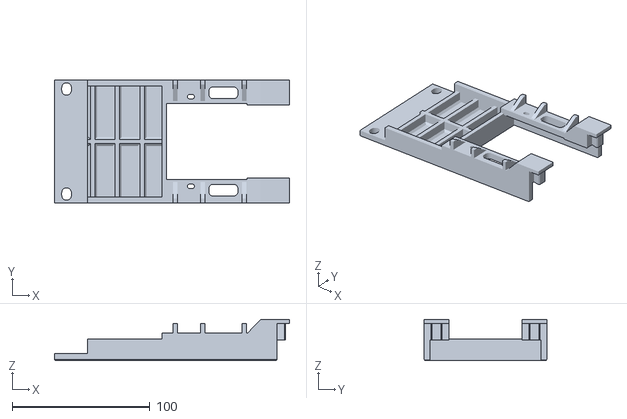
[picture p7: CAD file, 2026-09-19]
hardware/enclosure/v10/assembly-stl/rackticker-face-end-v10-assembly.stl
170.4 x 88.9 x 29.8

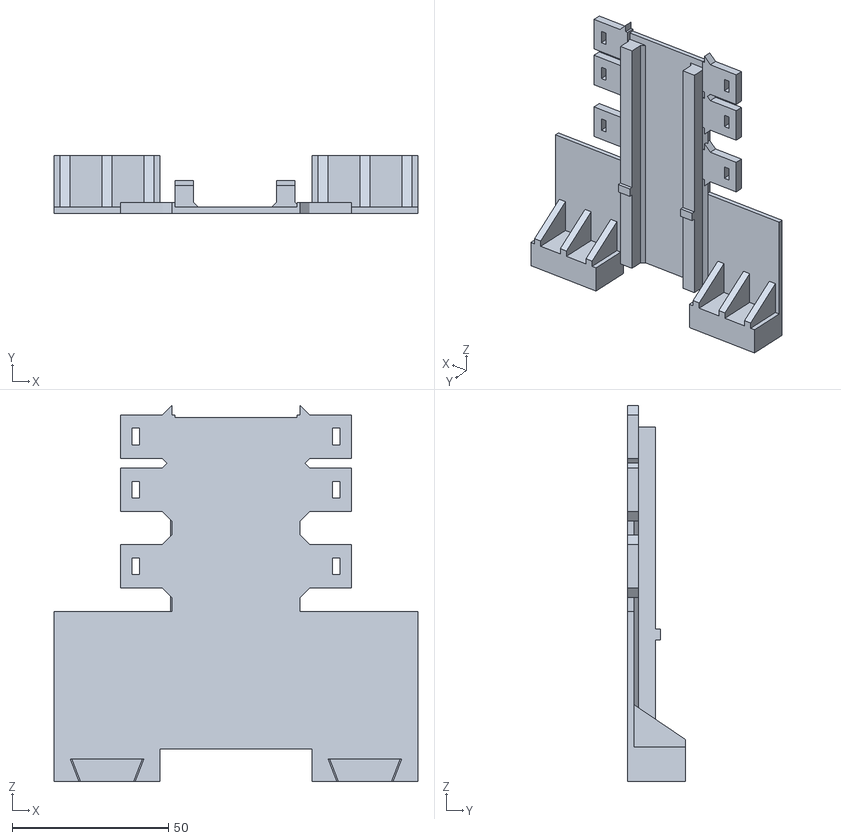
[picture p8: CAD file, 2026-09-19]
hardware/enclosure/v10/assembly-stl/rackticker-pi-cradle-v10-assembly.stl
116.6 x 18.5 x 120.5

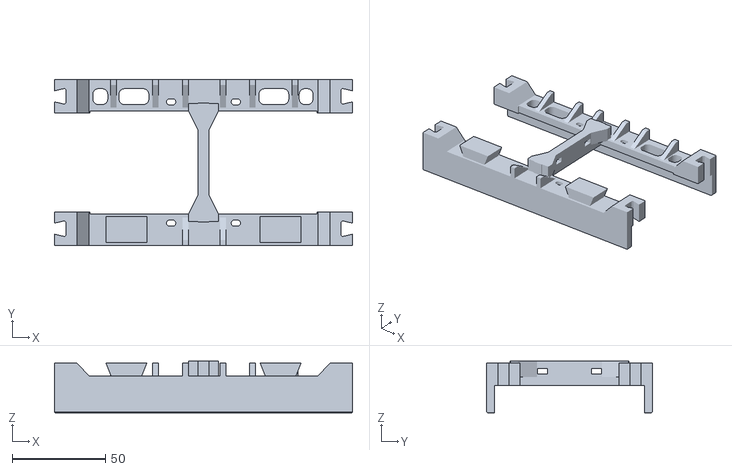
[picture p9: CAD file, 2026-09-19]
hardware/enclosure/v10/assembly-stl/rackticker-face-centre-v10-assembly.stl
159.7 x 88.9 x 27.8

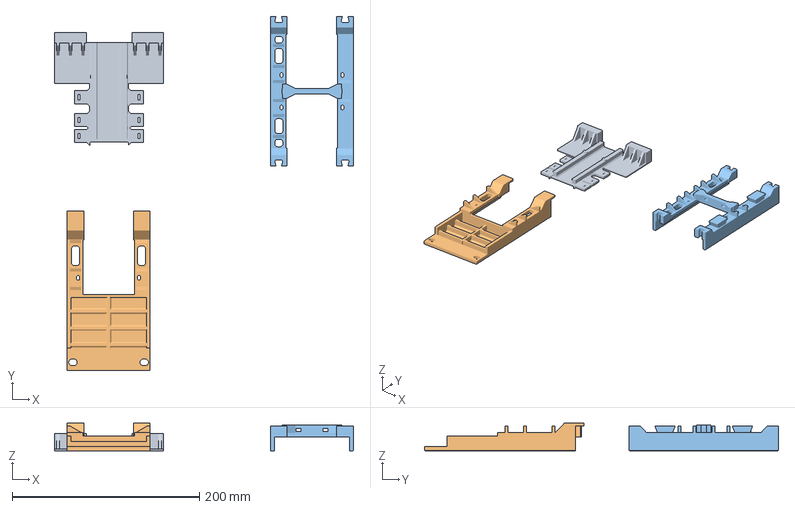
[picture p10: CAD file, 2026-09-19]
hardware/enclosure/v10/3mf/RackTicker.3mf
319.5 x 378.2 x 29.8 mm
rackticker-pi-cradle-v10.stl
rackticker-face-end-v10b.stl
rackticker-face-centre-v10.stl

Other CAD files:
hardware/enclosure/v10/assembly-stl/rackticker-face-end-left-v10-assembly.stl
hardware/enclosure/v10/step/rackticker-face-centre-v10.step
hardware/enclosure/v10/step/rackticker-face-end-v10b.step
hardware/enclosure/v10/step/rackticker-pi-cradle-v10.step
hardware/enclosure/v10/3mf/rackticker-face-centre-v10.3mf
hardware/enclosure/v10/3mf/rackticker-face-end-v10b.3mf
hardware/enclosure/v10/3mf/rackticker-pi-cradle-v10.3mf
hardware/enclosure/v10/stl/rackticker-face-centre-v10.stl
hardware/enclosure/v10/stl/rackticker-face-end-v10b.stl
hardware/enclosure/v10/stl/rackticker-pi-cradle-v10.stl

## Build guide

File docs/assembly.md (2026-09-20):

# Building a RackTicker

The whole build in order. The printing and mechanical fit are covered in detail in
[BEZEL_V10.md](../hardware/enclosure/BEZEL_V10.md); this page links each step to where it is
explained.

| The 2U face | Behind it |
| --- | --- |
| The printed 2U face | The Pi, adapter board and ADS-B receiver behind the face |

## 1. Parts

The full list, with quantities, is in
[BEZEL_V10.md](../hardware/enclosure/BEZEL_V10.md#what-you-need): two Waveshare 64×32 P2.5
panels, a Raspberry Pi 3A+, an RGB matrix adapter board, a 5 V supply with a barrel plug
(sized for your panels; 4 A or more is a good start), a microSD card, eight M3 × 10 screws,
four rack screws, a zip tie and about 220 g of PLA. An RTL-SDR ADS-B stick is optional.

## 2. Print the face

Four parts: two identical face ends, a face centre and a Pi cradle. Use the ready-oriented
files in `hardware/enclosure/v10/3mf/`, and print the cradle with supports **off**. Settings
and the reasons are in [BEZEL_V10.md](../hardware/enclosure/BEZEL_V10.md#print).

## 3. Set up the Pi

Flash Raspberry Pi OS Lite (64-bit), then run the installer. Both steps are in
[Install on a Pi](../README.md#install-on-a-pi).

## 4. Assemble

Fit the panels into the face and the Pi into its cradle following
[Assemble in BEZEL_V10.md](../hardware/enclosure/BEZEL_V10.md#assemble). Connect the adapter
board and the panels as the markings on your boards and the photo above show.

## 5. First light

1. Power it on. The panels show the address to use, by name and by IP.
2. Open `http://<address>:8081/` (port 8081 on a Pi, not 8080) and set your home location under
   Settings.
3. Press **Settings → Developer tools → Colour test** and check each block matches its label.

If the colours are wrong or the panel flickers, see
[Panel tuning](../README.md#panel-tuning). The two usual fixes are `--led-rgb-sequence=RBG`
when green shows blue, and keeping the default `--led-limit-refresh=120`.

## 6. Handing it over

Before boxing a unit for someone else, use **Settings → Software → Reset → Ready to pass on**.
See [Passing one on](../README.md#passing-one-on-or-cloning-cards).

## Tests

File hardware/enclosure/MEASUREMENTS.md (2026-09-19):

# Panel mounting dimensions and selected interface

Source: Waveshare's official `RGB-Matrix-P2.5-64x32-2D.dwg`, linked from
[Waveshare resources](https://docs.waveshare.com/RGB-Matrix-Px-64x32/Resources-And-Documents).
[Original drawing](https://github.com/waveshareteam/RGB-Matrix-Px-xx/blob/main/hardware/dimensions/RGB-Matrix-Pxx-64x32/RGB-Matrix-P2.5-64x32-2D.dwg).

Extracted with LibreDWG on 2026-09-14. Coordinates below describe the frame
view, with the lower-left outer edge as origin, in millimetres.

| Feature | Drawing value |
|---|---:|
| Frame outline | 159.70 × 79.70 (±0.30 annotations) |
| Nominal panel envelope | 160 × 80 |
| DWG small-hole centre spacing | 125 × 65 |
| DWG small-hole centres X | 17.35, 142.35 |
| DWG small-hole centres Y | 7.35, 72.35 |
| Large recess centres X (not the selected screw holes) | 7.35, 44.85, 79.85, 114.85, 152.35 |
| Large side recess centres Y | 39.85 |
| Frame section depth | 12 |
| Small corner hole circle diameter | 2.30 |

The drawing's diameter is not an explicit metric thread specification. Use the
supplied screws that already fit the inserts; do not infer allowable engagement
length from the 12 mm frame depth. Frame depth is not the complete powered-panel
connector envelope. An open rear mount avoids needing that envelope measured.

The earlier fit gauges are withdrawn because they made the reference edge
ambiguous. The selected mechanical interface is instead validated by the
MakerWorld 5 mm joiner the user printed for these panels. That listing states
35 mm centre-to-centre between the two seam screws, Ø3.5 mm clearance holes,
and M3×8 hardware. The rack ears therefore use 17.5 mm from each nominal panel
side, Ø3.6 × 6 mm tolerance slots, and 5 mm material thickness.

## Community references

[Joining brackets by jandj](https://www.printables.com/model/1294572-brackets-for-joining-hub75-led-panels)
describe 12 mm frames, 3 mm mounting holes and separate pin holes, but explicitly
say dimensions may require adjustment between panel types. They support the
mounting approach, not a universal mounting pattern.

[Desktop stand](https://www.printables.com/model/54027-desktop-stand-for-many-hub75-led-panels)
uses the grips of supplied magnetic screws and was tested with two Adafruit
models. Metal screws alone do not establish that the supplied heads are magnets.
A magnetic mount needs a ferromagnetic steel surface; a plastic frame cannot
retain magnets directly. The rack ears use original geometry rather than copied
community model geometry.

[MakerWorld panel brackets](https://makerworld.com/en/models/2422145-hub75-led-matrix-panel-bracket-mount-64x32-p2-5#profileId-2656417)
provide the physically tested interface used here: 35 mm seam spacing, Ø3.5 mm
holes, 5 mm plate thickness and M3×8 screws. RackTicker's C-shaped 2U ears are
original geometry and use only those stated compatibility dimensions.

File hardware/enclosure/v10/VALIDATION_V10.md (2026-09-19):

# RackTicker bezel v10 - validation report

`94 PASS`, `0 WARN`, `0 FAIL`

Generated by `validate_bezel_v4.py`. Every geometric check runs against
the serialized STL that the slicer receives, not the pre-export CAD body.

| Result | Check | Detail |
|---|---|---|
| PASS | 1 connected-body count [face-end] | 1 connected mesh component(s) after STL serialization (required exactly 1) |
| PASS | 2 closed solid [face-end] | watertight=True winding=True volume=69.91 cm3 |
| PASS | 3 A1 Mini bed fit [face-end] | print bbox 170.45 x 88.90 x 29.80 mm (bed 180 x 180) |
| PASS | 1 connected-body count [face-centre] | 1 connected mesh component(s) after STL serialization (required exactly 1) |
| PASS | 2 closed solid [face-centre] | watertight=True winding=True volume=61.98 cm3 |
| PASS | 3 A1 Mini bed fit [face-centre] | print bbox 159.70 x 88.90 x 27.80 mm (bed 180 x 180) |
| PASS | 1 connected-body count [pi-cradle] | 1 connected mesh component(s) after STL serialization (required exactly 1) |
| PASS | 2 closed solid [pi-cradle] | watertight=True winding=True volume=41.52 cm3 |
| PASS | 3 A1 Mini bed fit [pi-cradle] | print bbox 116.60 x 120.50 x 18.50 mm (bed 180 x 180) |
| PASS | 4 panel envelope vs face-end | left panel: 0.0000 mm3 unintended collision volume |
| PASS | 4 panel envelope vs face-end-left | left panel: 0.0000 mm3 unintended collision volume |
| PASS | 4 panel envelope vs face-centre | left panel: 0.0000 mm3 unintended collision volume |
| PASS | 4 panel envelope vs pi-cradle | left panel: 0.0000 mm3 unintended collision volume |
| PASS | 4 panel envelope total [left panel] | 0.0000 mm3 across the whole installed assembly |
| PASS | 4 panel envelope vs face-end | right panel: 0.0000 mm3 unintended collision volume |
| PASS | 4 panel envelope vs face-end-left | right panel: 0.0000 mm3 unintended collision volume |
| PASS | 4 panel envelope vs face-centre | right panel: 0.0000 mm3 unintended collision volume |
| PASS | 4 panel envelope vs pi-cradle | right panel: 0.0000 mm3 unintended collision volume |
| PASS | 4 panel envelope total [right panel] | 0.0000 mm3 across the whole installed assembly |
| PASS | 5 screw bearing [face-end X98.95 Y11.95] | 6/6 probes give 5.000-5.000 mm between Z=14.80 and Z=19.80 (required exactly 5.000) |
| PASS | 6 screw path open [face-end X98.95 Y11.95] | 0 mesh hit(s) on the screw axis (required 0) |
| PASS | 5 screw bearing [face-end X98.95 Y76.95] | 6/6 probes give 5.000-5.000 mm between Z=14.80 and Z=19.80 (required exactly 5.000) |
| PASS | 6 screw path open [face-end X98.95 Y76.95] | 0 mesh hit(s) on the screw axis (required 0) |
| PASS | 5 screw bearing [face-centre X223.95 Y11.95] | 6/6 probes give 5.000-5.000 mm between Z=14.80 and Z=19.80 (required exactly 5.000) |
| PASS | 6 screw path open [face-centre X223.95 Y11.95] | 0 mesh hit(s) on the screw axis (required 0) |
| PASS | 5 screw bearing [face-centre X223.95 Y76.95] | 6/6 probes give 5.000-5.000 mm between Z=14.80 and Z=19.80 (required exactly 5.000) |
| PASS | 6 screw path open [face-centre X223.95 Y76.95] | 0 mesh hit(s) on the screw axis (required 0) |
| PASS | 5 screw bearing [face-centre X258.65 Y11.95] | 6/6 probes give 5.000-5.000 mm between Z=14.80 and Z=19.80 (required exactly 5.000) |
| PASS | 6 screw path open [face-centre X258.65 Y11.95] | 0 mesh hit(s) on the screw axis (required 0) |
| PASS | 5 screw bearing [face-centre X258.65 Y76.95] | 6/6 probes give 5.000-5.000 mm between Z=14.80 and Z=19.80 (required exactly 5.000) |
| PASS | 6 screw path open [face-centre X258.65 Y76.95] | 0 mesh hit(s) on the screw axis (required 0) |
| PASS | 5 screw bearing [face-end-left X383.65 Y11.95] | 6/6 probes give 5.000-5.000 mm between Z=14.80 and Z=19.80 (required exactly 5.000) |
| PASS | 6 screw path open [face-end-left X383.65 Y11.95] | 0 mesh hit(s) on the screw axis (required 0) |
| PASS | 5 screw bearing [face-end-left X383.65 Y76.95] | 6/6 probes give 5.000-5.000 mm between Z=14.80 and Z=19.80 (required exactly 5.000) |
| PASS | 6 screw path open [face-end-left X383.65 Y76.95] | 0 mesh hit(s) on the screw axis (required 0) |
| PASS | 6 rack slot open [face-end Y6.35] | 0 mesh hit(s) on the rack screw axis (required 0) |
| PASS | 6 rack slot open [face-end Y82.55] | 0 mesh hit(s) on the rack screw axis (required 0) |
| PASS | 6 rack slot open [face-end-left Y6.35] | 0 mesh hit(s) on the rack screw axis (required 0) |
| PASS | 6 rack slot open [face-end-left Y82.55] | 0 mesh hit(s) on the rack screw axis (required 0) |
| PASS | 7 interference face-end / face-end-left | 0.0000 mm3 overlap |
| PASS | 7 interference face-end / face-centre | 0.0000 mm3 overlap |
| PASS | 7 interference face-end / pi-cradle | 0.0000 mm3 overlap |
| PASS | 7 interference face-end-left / face-centre | 0.0000 mm3 overlap |
| PASS | 7 interference face-end-left / pi-cradle | 0.0000 mm3 overlap |
| PASS | 7 interference face-centre / pi-cradle | 0.0000 mm3 overlap |
| PASS | 8 engagement face-end <-> face-centre | closest approach 0.000 mm - cap seated on the centre node, key in socket |
| PASS | 8 engagement face-end-left <-> face-centre | closest approach 0.000 mm - cap seated on the centre node, key in socket |
| PASS | 8 engagement face-centre <-> pi-cradle | closest approach 0.000 mm - cradle slot roofs hanging on both dovetail rails |
| PASS | 8 fastener count | 8 x M3x10, all into the panel inserts.  Nothing threads into plastic; the cradle hangs on printed dovetails, the laps need no fastener |
| PASS | 9 rack interior hidden | 0 of 67399 sampled front-face points outside the aperture are open (required 0) |
| PASS | 9 panel aperture clear | 0 of 102240 sampled points inside the 319.40 x 79.70 mm panel area are obstructed (required 0) |
| PASS | 9 aperture clearance measured | top 0.40-0.40; bottom 0.42-0.42; left 0.42-0.42; right 0.40-0.40  (target 0.40 mm per edge, measured on the serialized mesh at Z=0.80, behind the edge chamfers) |
| PASS | 9 aperture clearance | 0.40 mm per edge, even on all four sides; aperture 320.20 x 80.50 mm; panel frame face 2.80 mm behind the bezel front plane, LED tips about flush |
| PASS | 11 panel rear connector band clear | 0.0000 mm3 of printed material touches the panel rear between Y 18.0 and Y 70.0, where the HUB75 headers, the +5V terminal and the frame recesses are (required 0).  Excludes the 6.00 mm seam fin, which bears only on the two frame rims where the panels butt |
| PASS | 11 connector clearance depth | nearest printed material in that band is 4.50 mm behind the panel rear plane |
| PASS | 12 left = right, same print | face-end differs from itself flipped top-to-bottom by 0.005 mm3, so the left-hand piece is the same print rotated 180 deg (required ~0) |
| PASS | 13 Pi + HAT envelope clear | 0.000 mm3 of any part inside the 56.5 x 65.0 x 26 mm board stack (required 0) |
| PASS | 13 Pi access clear [Pi power / HDMI / audio side (-X), full stack height, 40 mm out] | 0.000 mm3 of printed material in the plug / card access zone (required 0) |
| PASS | 13 Pi access clear [USB-A end (rear)] | 0.000 mm3 of printed material in the plug / card access zone (required 0) |
| PASS | 13 Pi access clear [micro-SD end (front)] | 0.000 mm3 of printed material in the plug / card access zone (required 0) |
| PASS | 13 Pi access clear [HAT barrel jack side (+X), full stack height, 40 mm out] | 0.000 mm3 of printed material in the plug / card access zone (required 0) |
| PASS | 13 Pi access clear [HAT barrel plug room in front of the board (38 mm)] | 0.000 mm3 of printed material in the plug / card access zone (required 0) |
| PASS | 14 jigsaw key [right top] | tab 502/502 mm3 solid end-part material; 0.00 mm3 of centre inside it; 1561 mm3 of socket around it; head 8.0 > socket neck 5.90, so the joint cannot open more than 0.25 mm |
| PASS | 14 jigsaw key [right bottom] | tab 502/502 mm3 solid end-part material; 0.00 mm3 of centre inside it; 1561 mm3 of socket around it; head 8.0 > socket neck 5.90, so the joint cannot open more than 0.25 mm |
| PASS | 14 jigsaw key [left top] | tab 502/502 mm3 solid end-part material; 0.00 mm3 of centre inside it; 1561 mm3 of socket around it; head 8.0 > socket neck 5.90, so the joint cannot open more than 0.25 mm |
| PASS | 14 jigsaw key [left bottom] | tab 502/502 mm3 solid end-part material; 0.00 mm3 of centre inside it; 1561 mm3 of socket around it; head 8.0 > socket neck 5.90, so the joint cannot open more than 0.25 mm |
| PASS | 15 LC1 50 N push, face bending | I = 8760 mm4, M = 6032 N.mm, stress 8.6 MPa in-layer, safety factor 4.1 (panels ignored) |
| PASS | 15 LC1 key neck tension | 132 N per key over a 5 x 12 mm neck = 2.0 MPa in-layer, safety factor 17.2 |
| PASS | 15 LC2 cradle, 20 N at the USB end (103 mm arm) | I = 1212 mm4, stress 9.7 MPa in-layer, safety factor 3.6 |
| PASS | 15 LC2 dovetail rail neck | 56 N per rail across a 16 x 14.0 mm neck = 0.25 MPa ACROSS layers, safety factor 48 |
| PASS | 15 LC3 zip-tie tab bending | 7.0 MPa in-layer, safety factor 5.0 (root fillets not credited) |
| PASS | 14 socket wall | 4.75 mm below and 4.75 mm above the socket head (solid node and band), 12.0 mm deep; required >= 4.0 mm |
| PASS | 16 min wall 3.0 mm [face-end] | 0 section region(s) thinner than 3.0 mm (~7 lines), 0 mm2 total; sub-4 mm2 slivers at fillet toes are ignored |
| PASS | 16 min wall 3.0 mm [face-centre] | 0 section region(s) thinner than 3.0 mm (~7 lines), 0 mm2 total; sub-4 mm2 slivers at fillet toes are ignored |
| PASS | 16 min wall 3.0 mm [pi-cradle] | 0 section region(s) thinner than 3.0 mm (~7 lines), 0 mm2 total; sub-4 mm2 slivers at fillet toes are ignored |
| PASS | 17 cradle slides down onto its rails | cradle lifted 0.5-21.5 mm in 0.5 mm steps: max 0.000 mm3 of collision with any bezel part along the whole path (required 0) |
| PASS | 17 face-end drops onto the centre key | lifted 0.5-19.5 mm rearward in 0.5 mm steps: max 0.000 mm3 of collision with face-centre (required 0) |
| PASS | 17 face-end-left drops onto the centre key | lifted 0.5-19.5 mm rearward in 0.5 mm steps: max 0.000 mm3 of collision with face-centre (required 0) |
| PASS | 18 screw access [X98.95 Y11.95] | M3 head zone (6.6 dia x 3.2) 0.000 mm3, straight hex-key path (5 dia x 77 mm) 0.000 mm3 of obstruction by the bezel (required 0) |
| PASS | 18 screw access [X98.95 Y76.95] | M3 head zone (6.6 dia x 3.2) 0.000 mm3, straight hex-key path (5 dia x 77 mm) 0.000 mm3 of obstruction by the bezel (required 0) |
| PASS | 18 screw access [X223.95 Y11.95] | M3 head zone (6.6 dia x 3.2) 0.000 mm3, straight hex-key path (5 dia x 77 mm) 0.000 mm3 of obstruction by the bezel (required 0) |
| PASS | 18 screw access [X223.95 Y76.95] | M3 head zone (6.6 dia x 3.2) 0.000 mm3, straight hex-key path (5 dia x 77 mm) 0.000 mm3 of obstruction by the bezel (required 0) |
| PASS | 18 screw access [X258.65 Y11.95] | M3 head zone (6.6 dia x 3.2) 0.000 mm3, straight hex-key path (5 dia x 77 mm) 0.000 mm3 of obstruction by the bezel (required 0) |
| PASS | 18 screw access [X258.65 Y76.95] | M3 head zone (6.6 dia x 3.2) 0.000 mm3, straight hex-key path (5 dia x 77 mm) 0.000 mm3 of obstruction by the bezel (required 0) |
| PASS | 18 screw access [X383.65 Y11.95] | M3 head zone (6.6 dia x 3.2) 0.000 mm3, straight hex-key path (5 dia x 77 mm) 0.000 mm3 of obstruction by the bezel (required 0) |
| PASS | 18 screw access [X383.65 Y76.95] | M3 head zone (6.6 dia x 3.2) 0.000 mm3, straight hex-key path (5 dia x 77 mm) 0.000 mm3 of obstruction by the bezel (required 0) |
| PASS | 18 screws behind the Pi | X223.95 Y11.95, X258.65 Y11.95: reachable once the cradle is lifted off its rails by hand - no tools, and check 17 proves the path is clear |
| PASS | 18 M3 heads clear the cradle | all 8 heads (6.6 dia x 3.2, larger than a socket cap): 0.000 mm3 in the final pose, max 0.000 mm3 along the slide-down path; nearest cradle flange is 3.65 mm to the side and the cradle floor 7.30 mm behind the heads (required 0 collision) |
| PASS | 10 floating islands [face-end] | 0 layer region(s) with no contact to the layer below (149 layers at 0.20 mm) |
| PASS | 10 overhang area [face-end] | 22.44 cm2 of downward-facing new area - supports required |
| PASS | 10 floating islands [face-centre] | 0 layer region(s) with no contact to the layer below (139 layers at 0.20 mm) |
| PASS | 10 overhang area [face-centre] | 43.35 cm2 of downward-facing new area - supports required |
| PASS | 10 floating islands [pi-cradle] | 0 layer region(s) with no contact to the layer below (92 layers at 0.20 mm) |
| PASS | 10 overhang area [pi-cradle] | 3.05 cm2 of downward-facing new area - supports required |

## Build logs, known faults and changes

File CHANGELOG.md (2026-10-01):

# Changelog

All notable changes will be recorded here. RackTicker uses Semantic Versioning.

## Unreleased

- **"ADS-B flights" is now "Planes overhead"**, and says what it does: planes over you with no
  hardware, from free community feeds around your home location.
- **Use a receiver on another computer.** Paste its `aircraft.json` address (a PiAware, readsb,
  tar1090 or ultrafeeder box) into "Receiver on your network". A USB stick on the Pi itself is
  still found on its own, and the free feed still covers any gap.

## 1.7.0 - 2026-09-30

- **A tidy Plugins page.** Everything on the device is one A–Z list by name, each tagged Built
  in or Community, instead of separate piles sorted by internal id. "Get more" lists only the
  community plugins you do not have yet (it used to repeat every installed one at the top of
  the page), with the box for a GitHub link underneath.
- **Update installs the newest release, whatever the page showed.** The button sent the
  commit the page had cached, so a stale page asked for an older version and failed. The
  device now checks GitHub at the moment you press it and installs only if that is newer.

## 1.6.1 - 2026-09-30

- **The Software page no longer offers an older version as an update.** A RackTicker running
  ahead of the newest release (deployed straight from main) was told an update was available,
  and installing it failed with "not newer than the one installed". The page now asks GitHub
  whether the release really comes after the installed version.

## 1.6.0 - 2026-09-30

- **Sports alerts wait for the TV.** Live feeds run ahead of broadcast, so a goal could
  appear on the panel before it happened on screen. Scores, banners and celebrations are now
  held back together by a broadcast delay: 30 seconds by default, set with "Alert delay
  (match your TV)" in the sports settings.
- **Headlines you can actually read.** The news desk crawled every headline past in 2×
  letters at 30 px/s: ten letters on the panel at a time, two and a half a second, half a
  minute a headline. The desk now shows the whole headline in 5×7 mixed case, two lines
  (about forty letters) at a time, rolling up a line once the eye has had time to take it
  in: a typical headline reads in eight seconds. It is the new `headline` style and what
  `auto` shows, with the Times Square zipper every third visit. The zipper and the TV lower
  third still crawl, but their 2× letters now step two LEDs at a time at twice the speed,
  which looks just as smooth and halves the wait.
- `wrap_text(text, width, scale, mixed)` is in the plugin API: whole-word lines that fit.
- **A feed that is down is not asked every five seconds.** Each failure doubles the wait
  before the next try, up to a minute, bundled and installed plugins alike, and saving new
  settings asks again straight away. On the test rack a price link was being refused by its
  server ("too many requests") every five seconds, all day.
- **No half-second freeze when a plane comes into range.** The ADS-B receiver's files, and
  the aircraft database a new arrival is looked up in, are parsed in the helper process
  instead of on a thread that held up the display; installing a plugin unpacks its
  download off the display's loop too.
- Sportsbook: a team without a logo gets dark letters on a light team colour; Boston's gold
  had white letters that could not be read.
- **News: BREAKING only when a story has just broken.** ESPN stamps its stories EST all
  year, so in summer each one looked an hour in the future and stayed BREAKING for an hour.
  With every feed down the desk now says so instead of passing off old stories as fresh.
- **No provider timeouts every 17 minutes.** When the parsing helper retired, flights, sports
  and news all timed out together until its replacement had started; the next helper is now
  ready before it takes over.
- **Lighter on the Pi.** The network keeper no longer runs three `nmcli` calls every ten
  seconds, and a Home Assistant broker that cannot be found is reported once, with the fix
  (use Home Assistant's IP address; `core-mosquito` only resolves inside Home Assistant).
- **Nothing cut off mid-read.** A plane passing overhead waits for a crawling headline to
  finish its lap, and installed plugins finish the card on show when their turn ends.
- **Sportsbook**: team logos fill the panel height and stay readable; baseball's bases,
  count and outs are spread across the card; a single run no longer takes over the panel.
- **Flights** with no route on file show type, height, speed and distance on whole lines.
- **Pixel Town / Rackville**: waves roll in from the horizon, people walk when they move,
  keep their feet on the ground and no longer clip through the taco truck, and the camera
  follows somebody.
- Weather: fog is a cloud with mist under it. The news ticker fills the panel to its last row.
- Restarting a plugin also stops the programs it started (an `ffmpeg` could outlive it).
- Run with Python older than 3.10, RackTicker says so up front instead of failing deep in an
  import; a laptop without an ADS-B receiver asks for a location instead of naming a file.
- Plugin docs: installed screens are drawn ahead, so `render()` must depend only on its
  context. `fx.dim` and `fx.plot` are cheaper.

## 1.5.0 - 2026-09-20

- **Smoother, and no more freezes.** The rack's own log showed the display stalling for up
  to two and a half seconds at a time. The Pi 3A+ was short of memory and had pushed the
  display's own pages out to the SD card; every stall was it waiting to read them back. The
  Pi now uses compressed swap in RAM (`rackticker-memory.service`, best effort and only if the
  kernel has zram), the processes hand freed memory back to the system, and each stall the
  panel suffers is recorded in `/api/state` with what it was doing: computing, waiting for
  swap, or collecting garbage.
- **Screens from installed plugins scroll smoothly.** They are drawn a few frames ahead of the
  one on show, so a late reply no longer shows as a hitch in a crawl, and the previous screen
  stays up until a plugin's first picture is ready instead of flashing black between screens.
- **One stuck plugin no longer restarts all of them.** A hung plugin used to be declared on a
  single unanswered request and took every other installed plugin down with it, blanking the
  screen being read. The process is now only stopped after real silence.
- **Screens are not snatched away mid-read.** A screen that says it has nothing to show gets
  four seconds to change its mind (a feed that blinks, a plugin restarting), a plane's card is
  finished before the playlist moves on, one failed refresh is no longer called "cached", and
  a passing plane waits twelve seconds into the current screen before it takes over.
- **The stock tape and the news desk stop stuttering when data arrives.** New quotes swap
  into the crawl without it jumping, and the news desk draws its headline strips a little at
  a time instead of all at once.
- **News says BREAKING** for a story under a minute old: a flashing red chip and its own
  bumper, instead of "0M AGO". Stories under fifteen minutes old glow amber.
- **Flights** are one still card: the airline, the city it left and the city it is going to
  in full (airport codes small beside them), a progress bar with the aircraft on it, and the
  time left. Nothing scrolls or turns over any more.
- The random-dot dissolve is no longer in the automatic rotation of transitions: on an LED
  panel it reads as flicker.

## 1.4.0 - 2026-09-20

- **Flights** now know what the aircraft is. A plane does not transmit its type, so
  the receiver never had one; RackTicker now reads the aircraft database that
  dump1090 keeps beside its own web page, the way its map does. Every aircraft
  overhead resolved instantly on the test rack, with no network call.
- **Sportsbook** keeps the line up once a game is under way: the favourite, the
  spread and the total alternate with the channel. Off with Lines on live games.
- **The stock tape** sits out the weekend; there is a setting for market hours only.
- The README says up front that anyone can write a screen, and links the starter.
  It also no longer claims the control page has no password.

## 1.3.0 - 2026-09-19

- **Pixel Town**: people no longer walk through the taco truck — they pass behind
  it — and hungry ones form a real queue at the window instead of standing inside
  one another, wait their turn and leave with the taco in hand. The street they
  walk down is new too: a pavement, shadows underfoot, lit shopfronts with their
  own awnings, a cook in the serving window, steam off the griddle, vans in the
  traffic, birds by day and a cat at 3 AM.
- The control page's port is now stated plainly: 8080 on a computer, 8081 on a Pi.

## 1.2.0 - 2026-09-19

- Reset goes as far back as you need, from Settings: settings and plugins, Wi-Fi
  only (for when RackTicker moves without you), everything, or **Ready to pass on**
  — which also clears the system log, the shell history and the device's own
  identity, then powers off.
- A device now makes its own machine id, ssh host keys and name on first boot after
  that reset, named after its Pi (`rackticker-3c4d`). Cards cloned from one image
  no longer share an identity, an ssh host key or a `.local` name.
- A welcome step on first open: pick where the rack is and RackTicker sets its
  location and its clock in one go.
- **Restart the display** in Settings, for the times a restart is all it needs.
- The Status screen now reports this device instead of placeholders: whether it is
  really online, its own temperature, and a failed update, which used to be visible
  only on the control page.
- Photographs of a built unit in the README.

## 1.1.0 - 2026-09-19

- Set the time zone from Settings, no SSH: clocks, schedules and news timestamps
  follow it anywhere in the world.

## 1.0.11 - 2026-09-19

- Update now always re-checks GitHub first, and a device refuses to install a
  version older than the one it runs. A cached answer could install an older release.

## 1.0.10 - 2026-09-19

- The parsing helper is recycled, so it no longer grows to a third of the memory in use.

## 1.0.9 - 2026-09-19

- An install is no longer mistaken for a crash: rolling back needs repeated restarts
  outside an install, and the display gets long enough to stop.

## 1.0.8 - 2026-09-19

- Memory and priority limits per service: the display, an update or a plugin can no
  longer take the machine (or ssh) down with them.

## 1.0.7 - 2026-09-19

- Installing no longer risks running a 512 MB Pi out of memory: the display pauses
  during the work, the panel companion compiles gently, and the Pi gets swap.
- Flights: the aircraft type shows beside the destination when both will not fit.

## 1.0.6 - 2026-09-19

- Flights: one still card with the airline, the big route, both cities in full and
  the time left. Nothing cycles.

## 1.0.5 - 2026-09-19

- Night brightness: near-black backgrounds and unlit TIX cells stay dark instead of glowing.
- Departures: announcements crawl one LED a frame under a steady heading.

## 1.0.4 - 2026-09-19

- The unplug-three-times password reset counts real power-ups only.

## 1.0.3 - 2026-09-19

- Forgot the password? Unplug RackTicker as soon as its panel lights up, three
  times in a row, and it is cleared. No computer needed.
- Dark colours no longer flicker in scan lines at low night brightness.

## 1.0.2 - 2026-09-19

- Optional control-page password (Settings → Software); stored only as a salted hash.
- Repeated crashes switch RackTicker back to the previous version by itself.
- The system log is capped so years of running do not wear out the SD card.

## 1.0.1 - 2026-09-19

- Updates from the web page with automatic rollback, daily self-healing, factory
  reset, Wi-Fi setup mode, a boot splash with the control page's address, and a
  one-line installer. Devices update to the newest published release.
- Hockey and football like the broadcast: shots, power plays, empty nets, goal
  scorers; a field strip with the first-down line, timeouts and big-play banners.
- News skips stories older than 12 hours (adjustable) and leads with the newest.
- Fixed: a blank panel after installing the network keeper, plugin installs
  from GitHub reading partial downloads.

## 1.0.0 - 2026-09

The first public release.

- Plugin platform: plugins are folders; install from a GitHub link or the
  community list, update and remove from the page; installed plugins run
  sandboxed in their own process. `python -m app.dev new/check/preview/push`
  and AGENTS.md guides for building screens with AI coding agents.
- New control page: Now / Screens / Plugins / Settings, team pickers, place
  search, one home location, light and dark.
- Home Assistant over MQTT discovery: light, screen picker, Show switches,
  Next and Message, ready for Alexa and Google through Home Assistant.
- Flights redesigned as an airport board with real airline marks, airport
  names, aircraft names and route progress; stale routes rejected.
- Traffic finds everything from your location: CHP incidents, Caltrans
  message signs and drive times drawn the way the signs read.
- Sportsbook: TV-style bases, count and outs; down and distance; big-play
  banners, and take-overs when your teams score or make the play.
- Lowercase with true descenders and accents for names and headlines.
- New: Data from a link, and community plugins Departures (with station
  announcements), Tanks, Quakes, Surf and Now playing (album art, lyrics and a
  car-stereo analyser).
- The printable 2U rack face, revision 10: four parts, eight screws.
- Smoothness: providers on their own thread, parsing off the render loop,
  steady panel refresh and colour-order tuning via matrix.conf.

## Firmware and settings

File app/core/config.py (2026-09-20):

"""Strict configuration validation and atomic, human-editable JSON persistence."""
from __future__ import annotations

import copy
import json
import math
import os
import re
import tempfile
from pathlib import Path
from app.core.plugins import PluginRegistry, NAME

MODULES = ("clock", "tixclock", "flight", "sports", "message", "system_status", "test_pattern")
TRANSITIONS = ("cut", "slide_left", "slide_up", "ticker", "wipe", "dissolve", "drop", "auto")

DEFAULT_CONFIG = {
    "version": 1,
    # Switched-on plugins; null means every plugin that ships with RackTicker.
    "enabled_plugins": None,
    # Accept plugin zips pushed over the network (python -m app.dev push).
    "plugin_uploads": False,
    "plugins": {},
    # 30 px/s at 30 fps moves exactly one LED per frame: the smoothest crawl
    # a matrix can show. Other speeds step unevenly by construction.
    "display": {"brightness": 85, "scroll_speed": 30, "scroll_gap": 32,
                "transition": "auto", "transition_seconds": 0.5, "fps": 30,
                # Living-room friendly: dim automatically overnight.
                "night_mode": False, "night_brightness": 20, "night_start": "23:00", "night_end": "07:00"},
    "simulator": {"mode": "led", "zoom": "fit", "animation_speed": 1.0},
    # Home, for weather, nearby flights and traffic. Plugins whose own latitude
    # and longitude are left at 0 use this.
    "location": {"name": "", "latitude": 0.0, "longitude": 0.0},
    # Home Assistant via MQTT discovery (Mosquitto add-on or any broker).
    "home_assistant": {"enabled": False, "host": "", "port": 1883, "username": "", "password": "",
                       "name": "RackTicker", "discovery_prefix": "homeassistant"},
    "modules": {
        "clock": {"enabled": True, "hour_format": "12", "show_seconds": True, "style": "desk"},
        "tixclock": {"enabled": True, "hour_format": "12", "update_interval": 4, "show_label": False},
        "flight": {"enabled": True, "max_distance_miles": 10, "layout": "route"},
        "sports": {"enabled": True},
        "message": {"enabled": True, "title": "RACKTICKER",
                    "text": "WASHER FINISHED • FRONT DOOR OPEN", "scrolling": True},
        "system_status": {"enabled": True, "temperature_unit": "F"},
        "test_pattern": {"enabled": True},
    },
    "playlist": [
        {"id": "clock-1", "module": "clock", "duration": 8, "enabled": True, "mode": "normal"},
        {"id": "tixclock-1", "module": "tixclock", "duration": 20, "enabled": True, "mode": "normal"},
        {"id": "sports-1", "module": "sports", "duration": 10, "enabled": True, "mode": "normal"},
        {"id": "flight-1", "module": "flight", "duration": 10, "enabled": True, "mode": "conditional"},
        {"id": "clock-2", "module": "clock", "duration": 8, "enabled": True, "mode": "normal"},
        {"id": "message-1", "module": "message", "duration": 10, "enabled": True, "mode": "normal"},
        {"id": "status-1", "module": "system_status", "duration": 6, "enabled": True, "mode": "normal"},
    ],
}


class ConfigError(ValueError):
    pass


def number(value, low, high, label):
    if isinstance(value, bool) or not isinstance(value, (int, float)) or not math.isfinite(value) or not low <= value <= high:
        raise ConfigError(f"{label} must be a number from {low} to {high}")


def choice(value, options, label):
    if value not in options:
        raise ConfigError(f"{label} must be one of {', '.join(map(str, options))}")


def boolean(value, label):
    if not isinstance(value, bool):
        raise ConfigError(f"{label} must be true or false")


def merge_known(default, raw, path="config"):
    if not isinstance(raw, dict):
        raise ConfigError(f"{path} must be an object")
    extra = raw.keys() - default.keys()
    if extra:
        raise ConfigError(f"Unknown {path} setting: {sorted(extra)[0]}")
    result = copy.deepcopy(default)
    for key, value in raw.items():
        result[key] = merge_known(default[key], value, f"{path}.{key}") if isinstance(default[key], dict) else copy.deepcopy(value)
    return result


# Settings retired by later versions: dropped on load so older saved configs
# keep validating instead of failing on an unknown key.
RETIRED = {("modules", "flight", "radar_up")}


RETIRED_MODULES = {"iracing"}   # built-in screens that were removed


def retire(raw):
    modules = raw.get("modules") if isinstance(raw, dict) else None
    for name in RETIRED_MODULES:
        if isinstance(modules, dict):
            modules.pop(name, None)
        for key in ("playlist", "interrupts"):
            entries = raw.get(key) if isinstance(raw, dict) else None
            if isinstance(entries, list):
                raw[key] = [entry for entry in entries if not (isinstance(entry, dict) and entry.get("module") == name)]
    for path in RETIRED:
        node = raw
        for key in path[:-1]:
            node = node.get(key) if isinstance(node, dict) else None
        if isinstance(node, dict):
            node.pop(path[-1], None)
    return raw
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

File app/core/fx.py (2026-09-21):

"""Pixel-native LED signage effects: easing, colour, sprites, particles and
animated lettering.

Everything draws whole pixels on the frame; nothing antialiases. Effects are
pure functions of (seed, time) so every sink and emulator shows identical
pixels, while callers vary the seed per run so a sign never replays the same
"movie" twice.
"""
from __future__ import annotations

import colorsys
import math
import random
from functools import lru_cache

from PIL import Image

from app.core.fonts import glyph_spans, text_mask, text_width

WIDTH, HEIGHT = 128, 32
EFFECTS = ("assemble", "drop", "slot", "typewriter", "wave", "scroll_stop",
           "chomp", "split", "sparkle", "fireworks")


# --- easing and colour ------------------------------------------------------

def clamp01(value):
    return 0.0 if value <= 0 else 1.0 if value >= 1 else value


def ease_out(t):
    return 1 - (1 - clamp01(t)) ** 3


def ease_in(t):
    return clamp01(t) ** 3


def ease_in_out(t):
    t = clamp01(t)
    return 4 * t * t * t if t < .5 else 1 - (-2 * t + 2) ** 3 / 2


def bounce(t):
    t = clamp01(t)
    n, d = 7.5625, 2.75
    if t < 1 / d:
        return n * t * t
    if t < 2 / d:
        t -= 1.5 / d
        return n * t * t + .75
    if t < 2.5 / d:
        t -= 2.25 / d
        return n * t * t + .9375
    t -= 2.625 / d
    return n * t * t + .984375


def hsv(h, s=1.0, v=1.0):
    r, g, b = colorsys.hsv_to_rgb(h % 1.0, s, v)
    return (round(r * 255), round(g * 255), round(b * 255))


def dim(color, amount):
    r, g, b = color
    return (max(0, min(255, round(r * amount))), max(0, min(255, round(g * amount))),
            max(0, min(255, round(b * amount))))


def mix(a, b, t):
    t = clamp01(t)
    return tuple(round(x + (y - x) * t) for x, y in zip(a, b))


def plot(frame, pixels, x, y, color):
    """Max-blend one pixel so overlapping light adds up like real LEDs."""
    x, y = math.floor(x), math.floor(y)
    if x < 0 or y < 0:
        return
    try:
        old = pixels[x, y]
    except IndexError:              # off the right or bottom edge of the picture
        return
    pixels[x, y] = (max(old[0], color[0]), max(old[1], color[1]), max(old[2], color[2]))


# --- sprites -----------------------------------------------------------------

@lru_cache(maxsize=256)
def _sprite(art, palette, flip):
    colors = dict(palette)
    image = Image.new("RGBA", (max(map(len, art)), len(art)))
    pixels = image.load()
    for y, row in enumerate(art):
        for x, key in enumerate(row):
            if key in colors:
                pixels[x, y] = (*colors[key], 255)
    return image.transpose(Image.Transpose.FLIP_LEFT_RIGHT) if flip else image


def sprite(art, palette, flip=False):
    """ASCII art -> cached RGBA sprite. Characters missing from palette are clear."""
    return _sprite(tuple(art), tuple(sorted(palette.items())), flip)


def stamp(frame, image, x, y):
    frame.paste(image, (math.floor(x), math.floor(y)), image)


def triangle(frame, x, y, up, color):
    """A 5×3 market arrow; crisp at 1× where font arrows look spindly."""
    pixels = frame.load()
    rows = ((2, 2), (1, 3), (0, 4))
    for row, (left, right) in enumerate(rows if up else rows[::-1]):
        for column in range(left, right + 1):
            plot(frame, pixels, x + column, y + row, color)


# --- lights ------------------------------------------------------------------

@lru_cache(maxsize=8)
def _perimeter(width, height, inset):
    left, top, right, bottom = inset, inset, width - 1 - inset, height - 1 - inset
    points = [(x, top) for x in range(left, right)]
    points += [(right, y) for y in range(top, bottom)]
    points += [(x, bottom) for x in range(right, left, -1)]
    points += [(left, y) for y in range(bottom, top, -1)]
    return tuple(points)


def bulb_border(frame, t, colors, spacing=4, speed=10, inset=0):
    """Casino marquee: bulbs chase clockwise around the edge."""
    pixels = frame.load()
    phase = math.floor(t * speed + 1e-6)
    for index, (x, y) in enumerate(_perimeter(*frame.size, inset)):
        step = (index + phase) % spacing
        if step == 0:
            pixels[x, y] = colors[((index + phase) // spacing) % len(colors)]
        elif step == 1:
            pixels[x, y] = dim(colors[((index + phase) // spacing) % len(colors)], .22)


def chase_bar(frame, y, t, colors, segment=6, gap=3, speed=24, reverse=False):
    pixels = frame.load()
    period = segment + gap
    phase = math.floor(t * speed + 1e-6) % (period * len(colors))
    for x in range(frame.width):
        position = (x - phase if reverse else x + phase) % (period * len(colors))
        if position % period < segment:
            pixels[x, y] = colors[position // period]


# --- particles ---------------------------------------------------------------

class Particles:
    """Bounded, stateful particle field for simulations (games, confetti)."""

    def __init__(self, limit=360):
        self.items = []
        self.limit = limit

    def emit(self, x, y, vx, vy, life, color):
        if len(self.items) < self.limit:
            self.items.append([x, y, vx, vy, life, life, color])

    def burst(self, rng, x, y, count, speed, colors, life=(.5, 1.2), lift=0):
        for _ in range(count):
            angle = rng.random() * math.tau
            velocity = speed * (.35 + rng.random() * .65)
            self.emit(x, y, math.cos(angle) * velocity, math.sin(angle) * velocity - lift,
                      rng.uniform(*life), rng.choice(colors))

    def step(self, dt, gravity=0.0, drag=0.0):
        alive = []
        keep = max(0.0, 1 - drag * dt)
        for item in self.items:
            item[4] -= dt
            if item[4] <= 0:
                continue
            item[2] *= keep
            item[3] = item[3] * keep + gravity * dt
            item[0] += item[2] * dt
            item[1] += item[3] * dt
            if -8 < item[0] < WIDTH + 8 and item[1] < HEIGHT + 8:
                alive.append(item)
        self.items = alive

    def draw(self, frame):
        pixels = frame.load()
        for x, y, _, _, life, total, color in self.items:
            plot(frame, pixels, x, y, dim(color, .35 + .65 * life / total))


# --- lettering ---------------------------------------------------------------

@lru_cache(maxsize=128)
def text_points(text, scale=1, smooth=False):
    mask = text_mask(text, scale, smooth)
    pixels = mask.load()
    return tuple((x, y) for y in range(mask.height) for x in range(mask.width) if pixels[x, y])


@lru_cache(maxsize=128)
def point_letters(text, scale=1, smooth=False):
    """Letter index for each lit point, computed once instead of per pixel per frame."""
    spans = glyph_spans(text, scale)
    result = []
    for x, _ in text_points(text, scale, smooth):
        result.append(next((i for i, (_, start, width) in enumerate(spans) if start <= x < start + width), 0))
    return tuple(result)
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

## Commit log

2026-09-19 RackTicker 1.0.0
    Rack enhancement that fits in 2U: live LED signage for your server rack.
    [rackticker-face-centre-v10-assembly.stl, rackticker-face-centre-v10.3mf, rackticker-face-centre-v10.step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]
2026-09-19 Updates from the web page with automatic rollback, daily self-healing, factory reset, and a boot splash with the control page's address
    [runtime.py, source.py]
2026-09-19 Wi-Fi setup mode and network keeper, one-line Pi installer, self-healing no longer waits on the display service
    [runtime.py]
2026-09-19 Hockey like the broadcast: shots on goal, power play and its clock, empty net, goal calls with the scorer; baseball shows who is at bat
2026-09-19 Fresh installs start minimal: Traffic, F1 and Prediction markets ship switched off
2026-09-19 Fix blank panel: the network keeper had its own claim on /run/rackticker and re-owned the panel socket; installs now always restart the panel companion
    [RackTicker.3mf, rackticker-pi-cradle-v10.3mf]
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2026-09-19 RackTicker 1.0.2: optional password, crash-loop rollback, capped system log
    [source.py]
2026-09-19 RackTicker 1.0.3: password reset by unplugging three times; steady dark colours at night brightness
    [runtime.py, source.py]
2026-09-19 Quick-boot password reset counts power-ups only, not service restarts
2026-09-19 RackTicker 1.0.8: memory and priority limits so no part can take the device down
2026-09-19 RackTicker 1.0.9: installs are not mistaken for crashes
    [source.py]
2026-09-19 RackTicker 1.2.0: reset as far back as you need, and a device that stays itself
    Reset now has four depths, from settings to a unit ready to pass on: the deepest
    clears Wi-Fi, the password, plugin logins, the system log and shell history, then
    the machine id, ssh host keys and hostname, and powers off. The next boot makes
    new ones, named after the Pi's own serial, so cards cloned from one image come up
    as different devices instead of fighting over one address and one .local name.
    Anything past settings needs root, so the web app only asks; deploy/rackticker-reset.py
    does the work under systemd, as the updater does.
2026-09-19 Welcome step, restart from the page, and a Status screen that tells the truth
    First open now asks one question, where the rack is, and sets the location and the
    clock from the answer; everything else has a sensible default.
    Settings gains Restart the display, done by the root helper so it clears the
    restart counter first and is never mistaken for a crashing version.
    The Status screen reported INTERNET OK and a fixed temperature whatever was
    happening. It now reads the network keeper, this Pi's own thermal sensor, and the
    updater's last word, so a failed update is visible to someone who only ever looks
    at the panel.
    [models.py, runtime.py]
2026-09-19 The Status screen reads the keeper while it is fresh, and a stuck plugin stops shouting
    A plugin waiting to be logged in failed every few seconds and printed every time,
    which filled the log and wore the card for nothing; it says it once now, as the
    in-process providers already did.
    [runtime.py]
2026-09-20 Departures: Amtrak across the United States, and BART's colour-coded lines
    The board only knew seven European stations, which is a beautiful screen for
    someone who does not live near any of them. Two key-free sources answer that:
    Amtrak, through the Amtraker API, gives every Amtrak station in the country its
    own board, with the route's timetable name as the badge, the real destination,
    and the delay worked out from the scheduled against the estimated departure. A
    train that terminates at the station is an arrival, not a departure, and is left
    off, which is what the first version got wrong at Los Angeles Union.
    BART gives five lines calling every few minutes, each in its published colour,
    w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
2026-09-20 Metrolink boards, and the stock tape takes the weekend off
    Metrolink answers for every station on the system in one request, so a tour of
    its stations costs what one does, and its feed carries the Amtrak trains calling
    at the same platforms: an Orange County board shows both. A placeholder timestamp
    in that feed read as a train twenty-seven years late, so a drift of more than
    three hours is now treated as no information rather than as news.
    The stock tape showed Friday's closing prices all weekend. It now sits out
    Saturday and Sunday by default, with a setting for market hours only, or always.
    The README says up front that anyone can write a screen, and links the starter.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
2026-09-20 Onboard: the strip map inside the carriage, for a train that is really running
    The display above the doors: the line as a row of stops, the train sliding along
    it between the stop behind and the stop ahead by the clock it is actually
    keeping, the next stop and how long until it, and where the whole train is going.
    Amtrak's feed marks each stop called or still ahead, which is exactly what that
    display knows. Ride a named route, a train number, or whatever is serving a
    station code.
2026-09-20 README: the page has a password now, and a parts table is not the place for a wink
    The control page section still said there was no login, which stopped being true
    when Settings gained a password. The rack face's line said 'and yes, it'll fit';
    the useful fact is that it takes 88 mm of rack height.
2026-09-20 Surf: the sea is simulated instead of drawn
    The wave was a sine curve slid sideways, which is fine for a second and boring
    for ten. The bottom of the screen is now a row of springs with a wavemaker at the
    seaward edge, paced by the real swell period and sized by the real wave height:
    crests travel, meet, and break with foam on the steep face, and the whole sea
    still sits where the tide puts it.
    It starts primed, because a tank filling from flat wastes the first seconds of
    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
2026-09-20 Sportsbook: the line stays up once the game starts
    The board showed spreads and totals before kick-off and dropped them the moment
    the game went live, which is when the number is most interesting: a score is
    half a story without what the game was being measured against. Live cards now
    alternate the channel with the favourite, its spread and the total, in the same
    corner. Off with Lines on live games.
2026-09-20 Departures: a board that stuck on its announcement, and one that went blank
    Two faults behind the same screen sitting still.
    The board ran through its title, its pages and its announcements and then ran
    off the end: the last announcement's crawl left the screen and the heading stayed
    lit on its own for as long as the screen was up. It was a board stuck on AVVISO.
    The board now loops for as long as it is on show.
    Second, a station can hold a full timetable with nothing upcoming — every train
    gone, or the clock replaying a quiet hour — and the screen drew empty pages of
    nothing. Such a station is now skipped in favour of one with departures, and a
    board with nothing on it shows its name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
2026-09-20 Departures: the London Underground
    Four Tube stations, each line in the colour it is on the map and with the
    platform number off the sign. The Underground counts in seconds to the platform
    rather than clock times, so the board works back to a departure time; a train
    that will not say where it is going yet is left off rather than shown as 'check
    front of train'.
    The Northern line is black, which on a black panel is nothing at all, so its
    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
2026-09-20 The football field had three unused rows below it, and a flight had the wrong route
    The card stopped three rows short of the panel, so the field was a two-pixel
    sliver squeezed under the scores with the timeout pips on its last row. The card
    now runs to the bottom and the field is a proper strip: end zones, yard lines
    with a longer one at midfield, a round ball, the first-down line through it, and
    the timeouts below.
    Separately: a callsign is flown again every day, so the route ADSBDB has on file
    can belong to a different leg. One overhead read as Wichita Falls to South Bend,
    374 minutes to go, while it was minutes from landing in Orange County. A route
    whose two airports the aeroplane is n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
2026-09-20 Pixel Town: the panel is a camera on a town twice its width
    Rackville was exactly as wide as the panel, so it was a diorama. The town is now
    256 px across — nine shops, more people, a longer street — and the panel is a
    camera looking at part of it.
    The camera does not sweep on a timer, which reads as a machine. It settles on
    somewhere worth watching, stays while there is something to see, and glides on:
    the taco truck when a queue forms, a lit shopfront, the busiest stretch of
    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
2026-09-20 Flights: a jet that looks like one, and the time to go that fits
    The marker between the two airport codes was seven pixels: a cross with a bump on
    it. It is a thirteen-pixel jet now, with a tail fin at the back and a swept wing,
    pointing the way the route reads.
    The time to go said 5H19, which reads as a number cut off halfway, so it says
    5H19M. It also had nowhere to go on a card whose airline had a long name, so the
    name now gives up its room first: JetBlue 1524 becomes B6 1524 rather than the
    time disappearing. Both slots no longer draw it twice.
2026-09-20 Pixel Town: a beach with the real tide in it, and a station with real trains
    The town gets two more districts and the world goes to 384 across, with the
    panel still a camera on 128 of it.
    The beach is the sea as a band above and the sand as a band below, the way the
    town puts its buildings above its road; what moves is the line between them.
    The spring-water from the Surf plugin drives the wash running up the sand and
    draining back, sized by the real swell and set on the sand by the real tide,
    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
2026-09-20 Six more plugins move to the community repository
    Arcade, Formula 1, Prediction markets, LED sign, Freeway traffic and Data from
    a link now live in rackticker-community-plugins. Seven stay bundled so a unit
    is worth watching the moment it is switched on, offline. Their tests moved with
    them; the demo and clip audit pick them up when the community repo is beside us.
2026-09-20 Polish: a station house and moonlit sea in Pixel Town, signs that differ, a balanced clock, wind in km/h for Celsius
    The far end of the platform now has a station building with a working clock.
    On a clear night the moon lays a slow road of glitter on the water. The two
    rooftop signs stagger their messages. The classic clock's date no longer sits on
    the bottom row, and the weather screen shows wind in km/h when temperatures are
    in Celsius.
2026-09-20 README: shorter, with Pixel Town's three districts; a new demo GIF that tours the town
    The demo is now filmed on a weekday late morning wherever it runs, and Pixel Town stays
    long enough to visit the beach, the high street and the station. README trims: the plugin
    starter pitch appeared twice, the pass-it-on section and the install steps were wordier than
    they needed to be.
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2026-09-20 Pixel Town: a town with rules and some personality
    Cars now only exist on the road, coming out of and going back into a portal at each end, instead of
    driving onto the sand and down the railway. Walkers turn back at the tunnel wall unless they are
    catching a train, and the wall has a footpath door. Without the Departures plugin the town runs its
    own timetable and the trains arrive and leave on it. People duck into shops and come out with bags,
    open umbrellas in the rain, and a busker plays to the street. The beach has sunbathers and a kid
    flying a kite, and now and then a patrol car goes by with its lights going. Buildings are painted in
    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
2026-09-20 Flights: one clean card per aircraft, and a route even when the database has none
    The plane popup was three screens (a mostly black fly-by, a list and a card). It is now one full card per
    aircraft: airline and number, route, aircraft, altitude, speed, distance and time in the air, with the bottom line
    turning over through them. Route databases key on the callsign and airlines reuse them, so many airline flights had
    a wrong route or none; the provider now also asks a second source, checks every leg of it against where the aircraft
    is, and when nothing fits infers the airport the aircraft is landing at or has just left from its position, track,
    altitude and climb rate, shown as 'SNA' with '???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
2026-09-21 Smoother and steadier: installed screens drawn ahead, no black flash, a hang no longer restarts every plugin, screens are not snatched mid-read; BREAKING news; one still flight card
    The rack's own slow log showed two-second stalls, screens vanishing and every plugin
    restarting. Causes found and fixed:
    - Sandbox: frames are drawn a few ahead of the one on show, so a late reply is no longer a
    hitch in a crawl; the previous screen stays up until an installed plugin's first picture is
    ready (no black frame between screens); a process is only declared hung after real silence
    (one unanswered request used to restart every installed plugin, blanking the screen on show);
    static screens are s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
    [memory.py, renderer.py, runtime.py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]
2026-09-21 Docs for plugin authors on drawing ahead, memory and diagnostics tests, cheaper dim() and plot()
    - docs/plugins.md: an installed plugin's animated screen is drawn four frames ahead, so
    render() must depend only on its context; the hang rule is now process-wide silence.
    - tests for the memory service script, unit and installer wiring, and the stall record.
    - fx.dim and fx.plot avoid a generator and a Python-level size lookup per pixel.
    [fx.py]
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2026-09-22 Pixel Town: feet stay on the ground, and the camera hands over when somebody turns
    The walker rose a pixel on every other step, which read as a hop rather than a
    walk, and the step came every 1.6 px of ground, fast enough to flicker. Legs and
    arms swing on a 4 px stride instead and the body holds its height.
    The camera used to follow a walker who turned around all the way back, so the
    pan reversed with them and the town slid past twice. It now hands over when its
    subject turns, or once they have led it 70 px.
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2026-09-22 Pixel Town: people no longer clip through the taco truck or vanish mid-street on the way home, and joggers add some pace variety
    Walkers crossing the truck's footprint flickered through the gaps in its
    sprite outline instead of being cleanly hidden behind it. Beach-goers sent
    home after dark vanished the instant they came near any shop door, with no
    pause, and could in principle bounce forever between the shops and the sea
    wall if they never lined up with one. Also document what examples/ is for.
2026-09-23 Team logos on the sportsbook board fill the full panel height
    A 20px mark left crests like the Kings' crown reading as a smudge.
    Logos now draw straight onto the frame at full height, on top of the
    header, instead of being boxed into the scrolling card body — with a
    collision guard so the pregame odds don't smear when the bigger marks
    tighten the middle of the row.
2026-09-23 Sportsbook: baseball's bases/count/outs spread across the card, and a single run no longer takes over the panel
    The diamond, ball-strike count and outs were crowded into the top
    third of the card with the bottom rows empty. They now spread across
    the card's full height.
    Every single run a favorite team scored (a walk, a sac fly) triggered
    the full-panel fireworks takeover, same as a walk-off homer. In a
    high-scoring inning that meant the display kept cutting away from
    whatever else was on screen every time the Angels plated a run. A lone
    run now just banners on the card; a bigger inning still gets the
    takeover.
2026-09-23 Killing a plugin process takes what it started with it
    Each sandbox now leads its own process group and is killed as a group, so
    an ffmpeg or yt-dlp a plugin shelled out to can't outlive a restart. On the
    Pi a video_player restart had left ffmpeg stalled on a stream for minutes.
    [sandbox.py]
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2026-09-24 Headlines you can read at a glance, and a failing feed is not asked every five seconds
    The news desk crawled every headline past in 2x letters at 30 px/s: ten
    letters on the panel at a time, half a minute a headline. The new headline
    style (what auto now shows, with the zipper every third visit) puts the whole
    headline up in 5x7 mixed case, two lines at a time, rolling up a line once it
    has been read: a typical headline takes eight seconds. The 2x crawls that are
    left step two LEDs at a time at twice the speed. wrap_text() joins the plugin
    API for screens that want the same.
    A provider that fails is asked half as often each time, up to once a minute,
    in-process and in the sandbox, and new s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
    [fonts.py, runtime.py]
2026-09-24 No freeze as a plane comes into range, or while a plugin installs
    The rack's log showed a 600 ms stall each time a plane interrupted: the
    ADS-B provider parsed the receiver's JSON and the aircraft database files a
    new arrival is looked up in on a thread, and json.loads holds the GIL for
    all of it. Both now go through offload(), to the helper process.
    Installing a plugin unpacked the whole repository archive on the display's
    event loop, a second's freeze on a Pi; it is unpacked on a worker thread.
    [installer.py]
2026-09-30 No provider timeouts every 17 minutes when the parsing helper is replaced
    Python 3.11's own worker recycling left the pool with no helper for up to a
    minute after the old one retired, so flights, sports and news all timed out
    together every ~250 parses. The next helper is now started and has imported
    what the old one had before it takes over.
    [offload.py]
2026-10-01 RackTicker 1.6.0
    Devices only update to published GitHub Releases; 1.5.0 was bumped but never
    published, so they were stuck on 1.4.0. tools/publish_release.sh tags and
    publishes the version with its changelog section, and a test keeps
    pyproject.toml, __version__ and the changelog in step.
2026-10-06 RackTicker 1.8.0: a forgotten pause or preview no longer freezes the panel; routes must match what the plane is doing
    The rack sat on N338QT's card all night: a preview and a pause were left on, a
    plane alert started on top, and a paused scheduler never counted it down. Pause
    and preview now give the playlist back after 30 minutes, automatic alerts don't
    override a pause, and an alert started while paused still runs out.
    A route on file passed the old check whenever the plane was near the line
    between its airports, so a plane landing at LAX could show LAX to San Francisco.
    agrees() now drops a route whose destination isn't near an airport the plane is
    landing at, whose origin isn't near one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
2026-10-12 RackTicker 1.8.2: Wi-Fi power saving off, so the Pi stays on the network; the log really is kept across reboots
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2026-10-31 RackTicker 1.10.1: recover from blocked Wi-Fi without hours of downtime (#1)
    * Recover automatically from a persistently blocked Broadcom Wi-Fi driver
    * Release 1.10.1: bound Wi-Fi hang recovery and retain incident diagnostics
    * Include bundled store preview animations in release archives
    * Fix Windows rate-limit formatting and platform-specific checks
    ---------
